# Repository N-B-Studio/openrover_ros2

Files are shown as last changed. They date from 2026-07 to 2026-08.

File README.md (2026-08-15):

# OpenRover ROS 2

A modular, full-stack mobile robotics platform combining STM32 firmware, Linux-based robot software, ROS 2 middleware, SLAM, and autonomous navigation.

The project provides two embedded controller options and two onboard computer configurations. Each layer is designed to remain modular, allowing different controllers, computers, and LiDAR sensors to be combined without rewriting the complete software stack.

## Platform Configurations

### OpenRover Light

A compact 2D SLAM and navigation platform designed for learning, development, and low-cost deployment.

**Hardware**

* STM32F103 motor controller
* JC FOC motor drivers
* Radxa ROCK 5C
* LD06 2D LiDAR
* Differential-drive chassis

**Current capabilities**

* Keyboard teleoperation
* Wheel odometry
* ROS 2 TF publishing
* 2D LiDAR visualization
* SLAM map generation
* Map saving and loading
* Nav2-based autonomous navigation

# [Watch the video](https://youtu.be/SysfDb_uuPQ)

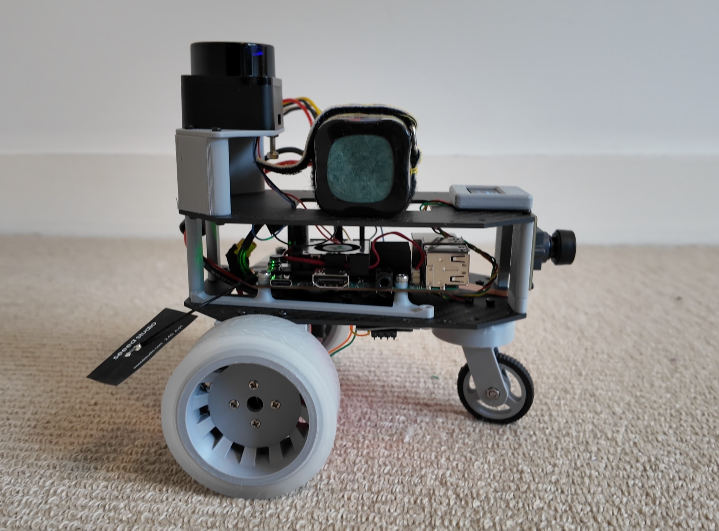
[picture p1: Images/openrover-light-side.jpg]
OpenRover Light side view


---

### OpenRover Plus

A higher-performance platform intended for 3D perception, sensor fusion, and more advanced autonomous robotics development.

**Planned hardware**

* STM32G431 motor controller
* Four integrated FOC wheel motors
* NVIDIA Jetson Orin Nano
* Livox Mid-360 3D LiDAR
* Intel RealSense D455 RGB-D camera
* BMI088 IMU

**Development goals**

* micro-ROS-based embedded communication
* Four-wheel skid-steer control
* IMU and wheel-odometry fusion
* 3D LiDAR SLAM
* RGB-coloured point clouds
* Autonomous exploration
* Navigation in unknown environments

**Status:** Under active development
**Demo video:** Coming soon
**Image:** Coming soon

## System Architecture

```mermaid
flowchart TD
    A["Sensors<br/>LD06 / Mid-360 / D455 / IMU"]
    B["Linux Computer<br/>ROCK 5C / Jetson Orin Nano"]
    C["ROS 2<br/>SLAM / Nav2 / Sensor Fusion"]
    D["Embedded Controller<br/>STM32F103 / STM32G431"]
    E["Motor Interface<br/>CAN / PWM + DIR"]
    F["FOC Motors"]

    A --> B
    B --> C
    C --> D
    D --> E
    E --> F
```

## Modular Design

OpenRover is not limited to fixed “Light” and “Plus” configurations.

The main components are designed as interchangeable layers:

| Layer | Available options |
| --- | --- |
| Embedded controller | STM32F103 or STM32G431 |
| Linux computer | Radxa ROCK 5C or NVIDIA Jetson Orin Nano |
| ROS 2 communication | UART text protocol or micro-ROS |
| LiDAR | LD06 2D LiDAR or Livox Mid-360 3D LiDAR |
| Camera | Intel RealSense D455 |
| Navigation | 2D SLAM and Nav2, with 3D autonomy planned |
| Motor control | CAN-based FOC control or 25 kHz PWM and direction control |

The long-term goal is to keep the ROS 2 interfaces consistent so that hardware components can be replaced without redesigning the entire application layer.

## Features

### Embedded Firmware

#### STM32F103

* CAN communication with FOC motor controllers
* UART command interface between Linux and STM32
* Plain-text velocity commands for debugging
* Motor command watchdog
* Wheel feedback reporting
* 0.96-inch OLED status display

#### STM32G431

* micro-ROS communication
* Four-wheel motor control
* 25 kHz PWM output
* Direction and brake control
* FG wheel-speed feedback
* Designed for odometry and diagnostic publishing

### ROS 2 Robot Software

* Differential-drive and skid-steer rover support
* `/cmd_vel` velocity command handling
* Wheel odometry publishing
* `odom -> base_link` TF publishing
* Robot description and RViz visualization
* Sensor drivers and launch files
* Keyboard teleoperation
* SLAM workflows
* Saved-map localization
* Nav2 navigation

### Perception and Autonomy

* LD06-based 2D mapping
* RViz goal-based navigation
* Obstacle-aware path planning
* Mid-360 3D perception integration — planned
* D455 RGB-D integration — planned
* RGB-coloured point-cloud mapping — planned
* Autonomous exploration — planned

## Repository Structure

```text
OpenRover/
├── G431CBU6-Rover/
│   └── STM32G431 rover firmware and related assets
├── STM32F103C8T6_ros2_car/
│   └── STM32F103 rover firmware
├── Linux/
│   └── ROS 2 workspaces, packages, launch files, and configuration
├── Ubuntu-22/
│   └── Additional Ubuntu-based ROS 2 development tools
├── Images/
│   └── Project photos, diagrams, and documentation assets
├── 3D model/
│   └── Rover chassis and wheel CAD assets
├── LICENSE
└── README.md
```

## Project Status

| Component | Status |
| --- | --- |
| STM32F103 motor control | Working |
| ROCK 5C ROS 2 integration | Working |
| Keyboard teleoperation | Working |
| Wheel odometry and TF | Working |
| LD06 visualization | Working |
| 2D SLAM | Working |
| Map saving and loading | Working |
| Nav2 integration | In progress |
| STM32G431 micro-ROS firmware | In progress |
| Four-wheel rover integration | In progress |
| IMU sensor fusion | Planned |
| Mid-360 3D SLAM | Planned |
| D455 colour point-cloud mapping | Planned |
| Autonomous exploration | Planned |

## Getting Started

Detailed setup guides will be provided for each supported configuration:

1. Build and flash the STM32 firmware.
2. Install ROS 2 on the onboard Linux computer.
3. Build the OpenRover ROS 2 workspace.
4. Connect the embedded controller and sensors.
5. Verify motor control, odometry, and TF.
6. Run teleoperation.
7. Build and save a map.
8. Launch localization and Nav2 navigation.

Configuration-specific instructions will be added under the relevant firmware and ROS 2 workspace directories.

## Roadmap

* [x] STM32F103 motor-control firmware
* [x] UART communication between ROS 2 and STM32
* [x] Wheel odometry and TF
* [x] LD06 integration
* [x] 2D SLAM workflow
* [ ] Complete and document Nav2 workflow
* [ ] Complete STM32G431 micro-ROS integration
* [ ] Add BMI088 IMU fusion
* [ ] Integrate Livox Mid-360
* [ ] Integrate Intel RealSense D455
* [ ] Generate RGB-coloured 3D point clouds
* [ ] Implement autonomous exploration
* [ ] Add automated tests and CI
* [ ] Publish complete build and demonstration videos

## Project Goals

OpenRover is both a practical robotics platform and a software-engineering portfolio project. It demonstrates experience across:

* C and C++ embedded development
* STM32 motor-control firmware
* ROS 2 node and interface design
* Linux robotics deployment
* Odometry and coordinate transforms
* SLAM and autonomous navigation
* Sensor integration and fusion
* Full-system debugging
* Simulation-to-real and hardware integration workflows

## License

This project is licensed under the MIT License. See [LICENSE](LICENSE) for details.

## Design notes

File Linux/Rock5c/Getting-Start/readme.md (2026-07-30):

# RoboNavLab DLC — LD06 2D SLAM & Autonomous Exploration

This DLC extends the frozen Stage 1 mobile base with an LD06 2D LiDAR, `slam_toolbox`, Nav2, and a frontier-exploration node.

## Final ROS 2 Architecture

```text
LD06
  |
  v
/scan ----------------------+
                            |
Stage 1 base                v
/cmd_vel <------------- Nav2 / Explorer
/odom ------------------+   |
/tf                     |   |
                        v   v
                    slam_toolbox
                        |
                        v
                      /map
                        |
                        +----> map_saver_cli
```

Target TF tree:

```text
map
└── odom
    └── base_link
        ├── left_wheel_link
        ├── right_wheel_link
        └── laser_frame
```

## Environment

Rock 5C:

```bash
source ~/ros2_humble/install/setup.bash
source ~/workspace/ros2_ws/install/setup.bash
export ROS_DOMAIN_ID=42
```

Ubuntu workstation:

```bash
source /opt/ros/<your-distro>/setup.bash
export ROS_DOMAIN_ID=42
```

## Start the Robot Base

On the Rock 5C:

```bash
ros2 launch ros_car_bringup car.launch.py
```

Verify:

```bash
ros2 topic hz /odom
ros2 topic echo /tf --once
ros2 run tf2_ros tf2_echo odom base_link
```

## Start the LD06 Driver

Run:
```bash
source ~/ros2_humble/install/setup.bash
source ~/workspace/ros2_ws/install/setup.bash
export ROS_DOMAIN_ID=42

ros2 run tf2_ros static_transform_publisher \
  --x -0.007 \
  --y 0.0 \
  --z 0.125 \
  --roll 0 \
  --pitch 0 \
  --yaw 0 \
  --frame-id base_link \
  --child-frame-id laser_frame
```

The final DLC will expose the LiDAR as:

```text
/scan
```

Verify:

```bash
ros2 topic list | grep scan
ros2 topic hz /scan
ros2 topic echo /scan --once
```

The `LaserScan.header.frame_id` must match the LiDAR TF frame, for example:

```text
laser_frame
```

## Start 2D SLAM

After the DLC packages and configuration are built:

```bash
ros2 launch ros_car_navigation slam.launch.py
```

Verify:

```bash
ros2 topic list | grep map
ros2 run tf2_ros tf2_echo map odom
```

Expected important topics:

```text
/scan
/odom
/map
/map_metadata
/tf
/tf_static
```

## Manual Mapping Test

Use keyboard teleoperation from the workstation:

```bash
ros2 run teleop_twist_keyboard teleop_twist_keyboard
```

Drive slowly around the room and verify that the occupancy grid grows in RViz.

Recommended RViz displays:

```text
Map        -> /map
LaserScan  -> /scan
RobotModel
TF
Odometry
```

Set:

```text
Fixed Frame = map
```

## Save the Map Locally

Create a map directory:

```bash
mkdir -p ~/workspace/ros2_ws/maps
```

Save the current occupancy map:

```bash
ros2 run nav2_map_server map_saver_cli \
  -f ~/workspace/ros2_ws/maps/room
```

Expected files:

```text
~/workspace/ros2_ws/maps/room.yaml
~/workspace/ros2_ws/maps/room.pgm
```

## Start Autonomous Exploration

After the exploration lesson is complete:

```bash
ros2 launch ros_car_navigation explore.launch.py
```

The exploration node will:

1. Read the current occupancy grid.
2. Find frontiers between known free space and unknown space.
3. Select a reachable frontier.
4. Send a Nav2 `NavigateToPose` goal.
5. Wait for the robot to reach or fail the goal.
6. Select the next frontier.
7. Stop when no useful frontiers remain.

Keep an emergency-stop terminal ready:

```bash
ros2 topic pub --once /cmd_vel geometry_msgs/msg/Twist "{}"
```

For first autonomous tests, keep the robot in a clear room and use conservative speed limits.

## Save the Automatically Built Map

When exploration is finished:

```bash
ros2 run nav2_map_server map_saver_cli \
  -f ~/workspace/ros2_ws/maps/room_auto
```

## Basic Health Checks

```bash
ros2 node list
ros2 topic hz /scan
ros2 topic hz /odom
ros2 topic hz /map
ros2 run tf2_ros tf2_echo odom base_link
ros2 run tf2_ros tf2_echo base_link laser_frame
ros2 run tf2_ros tf2_echo map odom
```

## Expected Final Packages

```text
ros_car_base/          # Stage 1 base driver
ros_car_description/   # URDF / TF
ros_car_bringup/       # Stage 1 bringup
ros_car_lidar/         # LD06 launch/config
ros_car_navigation/    # slam_toolbox + Nav2 + map save
ros_car_exploration/   # frontier explorer
```

## Final Demo

```text
Power on robot
    |
    v
Stage 1 bringup
    |
    v
LD06 /scan
    |
    v
slam_toolbox
    |
    v
Nav2 + frontier exploration
    |
    v
Robot autonomously explores room
    |
    v
room_auto.yaml + room_auto.pgm
```

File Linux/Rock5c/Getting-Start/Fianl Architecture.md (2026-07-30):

Robot: Rock 5C
────────────────────────────
STM32 base controller
LD06 driver
base_driver
robot_state_publisher
static/dynamic TF publishers
hardware watchdog
sensor diagnostics

Publishes:
  /scan
  /odom
  /tf
  /tf_static
  /joint_states
  /diagnostics

Subscribes:
  /cmd_vel

             DDS network

Workstation: Ubuntu PC
────────────────────────────
RViz
slam_toolbox
map saver
Nav2
rosbag2
diagnostic tools
later perception workloads

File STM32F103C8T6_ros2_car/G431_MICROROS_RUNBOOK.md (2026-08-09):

# G431 Four-Wheel Rover Base — micro-ROS Runbook

Status: **frozen baseline (`g431-base-v1.0`)**  
Target: STM32G431 + Jetson, ROS 2 Humble, micro-ROS serial transport

## 1. Frozen ROS 2 interface

The MCU intentionally exposes only the minimum base interface:

| Direction | Topic | Type | Purpose |
|---|---|---|---|
| Jetson → G431 | `/cmd_vel` | `geometry_msgs/msg/Twist` | Linear and angular velocity command |
| G431 → Jetson | `/wheel_states` | `sensor_msgs/msg/JointState` | Four-wheel position and velocity feedback |

Expected node name:

```text
/g431_rover_base
```

`/wheel_states` joint order:

```text
front_left_wheel_joint
rear_left_wheel_joint
front_right_wheel_joint
rear_right_wheel_joint
```

## 2. Safety and timing contract

- The MCU stops the motors if no `/cmd_vel` arrives for **200 ms**.
- The command source must continuously publish at **10–20 Hz**; **20 Hz is recommended**.
- Do not use 2 Hz: one message arrives every 500 ms, so the 200 ms watchdog repeatedly stops the motors for about 300 ms. This causes the observed start-stop motion and is expected behavior.
- The firmware retains the **300 ms direction-change protection**, 30 RPM limit, and calibrated PWM–RPM mapping.
- Stopping the command publisher must stop the rover within approximately 200 ms.
- This software watchdog is not a substitute for a physical emergency stop.

## 3. One-time Jetson prerequisites

Confirm the serial device:

```bash
ls -l /dev/ttyACM0
```

Confirm the user can access it:

```bash
groups
```

If the device changes after reconnecting, identify it with:

```bash
ls -l /dev/serial/by-id/
```

Prefer the stable `/dev/serial/by-id/...` path in scripts when available.

## 4. Start the native micro-ROS Agent

Terminal 1:

```bash
source /opt/ros/humble/setup.bash

ros2 run micro_ros_agent micro_ros_agent serial \
  --dev /dev/ttyACM0 \
  -b 115200 \
  -v4
```

Keep this terminal running while the G431 communicates with ROS 2. Only one Agent may open the serial port at a time.

For detailed diagnosis, temporarily replace `-v4` with `-v6`.

## 5. Optional Docker Agent

Use this only if the native Agent is unavailable. Do not run it at the same time as the native Agent.

```bash
docker run -it --rm \
  --net=host \
  --privileged \
  -v /dev:/dev \
  microros/micro-ros-agent:humble \
  serial \
  --dev /dev/ttyACM0 \
  -b 115200 \
  -v4
```

## 6. Verify the frozen interface

Terminal 2:

```bash
source /opt/ros/humble/setup.bash
source ~/workspace/ros2_ws/install/setup.bash

ros2 daemon stop
ros2 daemon start
ros2 node info /g431_rover_base
ros2 topic list -t
```

Expected node interface:

```text
Subscribers:
  /cmd_vel: geometry_msgs/msg/Twist
Publishers:
  /wheel_states: sensor_msgs/msg/JointState
```

Verify feedback:

```bash
ros2 topic hz /wheel_states
```

Expected rate: approximately **10 Hz** (measured baseline: **9.92 Hz**).

```bash
ros2 topic echo /wheel_states --once
```

Confirm:

- `header.stamp` is non-zero;
- `frame_id` is `base_link`;
- all four joint names are present;
- positions accumulate when wheels rotate;
- velocities update with the correct sign.

## 7. Safe bench motion test

Raise all four wheels off the ground before the first test.

Forward at 20 Hz:

```bash
ros2 topic pub -r 20 /cmd_vel geometry_msgs/msg/Twist \
  "{linear: {x: 0.10}, angular: {z: 0.0}}"
```

Stop the publisher with `Ctrl+C`. The wheels must stop within approximately 200 ms.

Pure rotation test:

```bash
ros2 topic pub -r 20 /cmd_vel geometry_msgs/msg/Twist \
  "{linear: {x: 0.0}, angular: {z: 0.5}}"
```

Publish an explicit zero command if required:

```bash
ros2 topic pub --once /cmd_vel geometry_msgs/msg/Twist \
  "{linear: {x: 0.0}, angular: {z: 0.0}}"
```

## 8. Check the command source

While teleoperation or autonomy is active:

```bash
ros2 topic hz /cmd_vel
```

Healthy baseline:

```text
average rate: approximately 20 Hz
min/max interval: approximately 0.050 s
```

Long gaps greater than 0.200 s trigger the watchdog. A low average caused by stopping and restarting the publisher is not a transport fault; inspect the `max` interval and observe the rate while commands are actively being sent.

## 9. Common faults

### `/wheel_states` is listed but no samples arrive

- Confirm the Agent is still running.
- Confirm the G431 is powered and connected.
- Ensure only one Agent owns `/dev/ttyACM0`.
- Restart the Agent, power-cycle the G431, and repeat the interface check.
- Use Agent verbosity `-v6` for entity-creation and transport logs.

### Two nodes have the same `/g431_rover_base` name

Stop duplicate Agents, then refresh discovery:

```bash
ros2 daemon stop
ros2 daemon start
```

Power-cycle the G431 and start exactly one Agent.

### Motors pulse or repeatedly start and stop

Measure `/cmd_vel`. If it is below 5 Hz or has gaps over 200 ms, the watchdog is operating correctly. Run the command source continuously at 10–20 Hz; 20 Hz is recommended.

### Agent reports that the serial port is busy

Find the process holding it:

```bash
lsof /dev/ttyACM0
```

Stop the older Agent process before starting another one.

## 10. Freeze checklist

Before tagging the repository:

- Release firmware builds and flashes successfully.
- `/g431_rover_base` has exactly one subscriber and one publisher.
- `/wheel_states` is stable near 10 Hz.
- Joint names, timestamp, frame, positions, and velocities are valid.
- A fixed command at 20 Hz produces smooth motion.
- Ending `/cmd_vel` publication stops the base within about 200 ms.
- Forward, reverse, and pure rotation directions are correct with the rover lifted.
- Firmware source, CubeMX configuration, linker/micro-ROS files, and this runbook are committed together.

Suggested Git tag:

```bash
git tag -a g431-base-v1.0 -m "Freeze G431 micro-ROS rover base interface"
git push origin g431-base-v1.0
```

Do not change the frozen MCU interface during the next stage. Implement odometry and TF on the Jetson using `/wheel_states` as the input.

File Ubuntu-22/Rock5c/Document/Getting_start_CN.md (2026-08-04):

下面是一套从零开始、按终端编号执行的完整流程。照这个顺序启动，就不会再丢步骤。

# A. Rock 5C 端

## Terminal R1 — 启动小车基础节点

```bash
source ~/ros2_humble/install/setup.bash
source ~/workspace/ros2_ws/install/setup.bash

export ROS_DOMAIN_ID=42
export ROS_LOCALHOST_ONLY=0
```

启动你现有的 Stage 1 bringup：

```bash
ros2 launch ros_car_bringup car.launch.py
```

如果你的 launch 文件名不是这个，使用你之前已经能启动：

```text
/base_driver
/robot_state_publisher
```

的那个命令。

验证：

```bash
ros2 node list
```

至少应看到：

```text
/base_driver
/robot_state_publisher
```

检查里程计：

```bash
ros2 topic hz /odom
```

目标：

```text
约 44 Hz
```

---

## Terminal R2 — 启动 LD06

```bash
source ~/ros2_humble/install/setup.bash
source ~/workspace/ros2_ws/install/setup.bash

export ROS_DOMAIN_ID=42
export ROS_LOCALHOST_ONLY=0
```

启动：

```bash
ros2 launch ldlidar ldlidar.launch.py \
  serial_port:=/dev/ttyS6 \
  lidar_frame:=laser_frame \
  topic_name:=scan
```

正常日志应包含：

```text
Using port /dev/ttyS6
LiDAR_LD06 started successfully
```

保持该终端运行。

---

## Terminal R3 — 发布 LiDAR 静态 TF

```bash
source ~/ros2_humble/install/setup.bash
source ~/workspace/ros2_ws/install/setup.bash

export ROS_DOMAIN_ID=42
export ROS_LOCALHOST_ONLY=0
```

运行：

```bash
ros2 run tf2_ros static_transform_publisher \
  --x -0.007 \
  --y 0.0 \
  --z 0.125 \
  --roll 0 \
  --pitch 0 \
  --yaw 1.57079632679 \
  --frame-id base_link \
  --child-frame-id laser_frame
```

保持该终端运行。

---

## Terminal R4 — Rock 端总检查

```bash
source ~/ros2_humble/install/setup.bash
source ~/workspace/ros2_ws/install/setup.bash

export ROS_DOMAIN_ID=42
export ROS_LOCALHOST_ONLY=0
```

检查 `/scan`：

```bash
ros2 topic hz /scan
```

应约为：

```text
10 Hz
```

检查 `/odom`：

```bash
ros2 topic hz /odom
```

应约为：

```text
44 Hz
```

检查完整 TF：

```bash
ros2 run tf2_ros tf2_echo odom laser_frame
```

应持续输出类似：

```text
Translation: [-0.007, 0.000, 0.125]
```

如果这三项通过，Rock 端完成。

不要在 Rock 上启动：

```bash
ros2 launch ros_car_navigation slam.launch.py
```

因为 SLAM 由 laptop 运行。

---

# B. Laptop 端

## Terminal P1 — 检查 Rock 数据

```bash
source /opt/ros/humble/setup.bash

export ROS_DOMAIN_ID=42
export ROS_LOCALHOST_ONLY=0
```

建议重启 daemon：

```bash
ros2 daemon stop
sleep 2
ros2 daemon start
sleep 2
```

检查雷达：

```bash
ros2 topic hz /scan
```

应约为：

```text
10 Hz
```

检查里程计：

```bash
ros2 topic hz /odom
```

应约为：

```text
44 Hz
```

检查 TF：

```bash
ros2 run tf2_ros tf2_echo odom laser_frame
```

必须持续输出。

只有这三项都正常，才继续 SLAM。

---

## Terminal P2 — 启动 SLAM Toolbox

```bash
source /opt/ros/humble/setup.bash

export ROS_DOMAIN_ID=42
export ROS_LOCALHOST_ONLY=0
```

启动：

```bash
ros2 launch slam_toolbox online_async_launch.py \
  use_sim_time:=false \
  slam_params_file:=$HOME/workspace/ros_car_demo/config/slam_params.yaml
```

保持运行。

正常日志应包含：

```text
Using solver plugin solver_plugins::CeresSolver
```

---

## Terminal P3 — 检查 SLAM

```bash
source /opt/ros/humble/setup.bash

export ROS_DOMAIN_ID=42
export ROS_LOCALHOST_ONLY=0
```

检查地图 topic：

```bash
ros2 topic list | grep -E "map|scan"
```

应看到：

```text
/map
/map_metadata
/scan
```

检查 SLAM 是否订阅 `/scan`：

```bash
ros2 topic info /scan -v
```

应至少有：

```text
Publisher count: 1
Subscription count: 1
```

检查 `map -> odom`：

```bash
ros2 run tf2_ros tf2_echo map odom
```

一旦这个开始持续输出，说明 SLAM 正常工作。

---

## Terminal P4 — 启动 RViz2

```bash
source /opt/ros/humble/setup.bash

export ROS_DOMAIN_ID=42
export ROS_LOCALHOST_ONLY=0

rviz2
```

RViz 设置：

```text
Fixed Frame = map
```

添加：

```text
Map
LaserScan
RobotModel
TF
Odometry
Grid
```

对应 Topic：

```text
Map        = /map
LaserScan  = /scan
Odometry   = /odom
```

如果刚启动时提示：

```text
Frame [map] does not exist
```

先等待几秒。

如果仍然不存在，回 Terminal P3 检查：

```bash
ros2 run tf2_ros tf2_echo map odom
```

---

## Terminal P5 — 键盘控制建图

```bash
source /opt/ros/humble/setup.bash

export ROS_DOMAIN_ID=42
export ROS_LOCALHOST_ONLY=0
```

启动：

```bash
ros2 run teleop_twist_keyboard teleop_twist_keyboard
```

按键：

```text
i = 前进
, = 后退
j = 左转
l = 右转
k = 停止
```

建议速度：

```text
Linear  = 0.10–0.15 m/s
Angular = 0.20–0.30 rad/s
```

推荐建图路线：

```text
1. 静止 5–10 秒
2. 缓慢直行
3. 缓慢转弯
4. 沿房间边缘走
5. 尽量回到起点
6. 等待 loop closure
```

避免：

```text
快速旋转
急加速
轮胎打滑
抬起机器人
手推机器人
```

---

# C. 地图不好时重新开始

只停止 laptop 上的 SLAM Toolbox。

在 Terminal P2 按：

```text
Ctrl+C
```

然后重新运行：

```bash
ros2 launch slam_toolbox online_async_launch.py \
  use_sim_time:=false \
  slam_params_file:=$HOME/workspace/ros_car_demo/config/slam_params.yaml
```

这会创建一张新的空地图。

以下节点不需要重启：

```text
Rock base_driver
Rock robot_state_publisher
Rock LD06
Rock laser TF
Laptop RViz
Laptop keyboard teleop
```

RViz 可以保持打开。

---

# D. 保存地图

## Terminal P6 — 保存最终地图

```bash
source /opt/ros/humble/setup.bash

export ROS_DOMAIN_ID=42
export ROS_LOCALHOST_ONLY=0
```

创建目录：

```bash
mkdir -p ~/workspace/ros_car_demo/maps
```

保存：

```bash
ros2 run nav2_map_server map_saver_cli \
  -f ~/workspace/ros_car_demo/maps/room_map
```

生成：

```text
~/workspace/ros_car_demo/maps/room_map.yaml
~/workspace/ros_car_demo/maps/room_map.pgm
```

检查：

```bash
ls -lh ~/workspace/ros_car_demo/maps
```

---

# 最终启动顺序速查

## Rock 5C

```text
R1: base bringup
R2: LD06
R3: base_link -> laser_frame
R4: diagnostics
```

## Laptop

```text
P1: verify /scan, /odom, TF
P2: slam_toolbox
P3: verify /map and map -> odom
P4: RViz2
P5: keyboard teleop
P6: save map
```

最关键的启动顺序是：

```text
1. Rock base
2. Rock LD06
3. Rock laser TF
4. Laptop verify data
5. Laptop SLAM
6. Laptop verify map -> odom
7. Laptop RViz
8. Laptop keyboard control
9. Save map
```

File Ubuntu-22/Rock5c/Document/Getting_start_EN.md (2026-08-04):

====================== Rock 5c: =====================
## terminal 1:
source ~/ros2_humble/install/setup.bash
source ~/workspace/ros2_ws/install/setup.bash

export ROS_DOMAIN_ID=42
export ROS_LOCALHOST_ONLY=0

ros2 launch ros_car_navigation explore.launch.py

## terminal 2:
source ~/ros2_humble/install/setup.bash
source ~/workspace/ros2_ws/install/setup.bash
export ROS_DOMAIN_ID=42

ros2 run tf2_ros static_transform_publisher \
  --x -0.007 \
  --y 0.0 \
  --z 0.125 \
  --roll 0 \
  --pitch 0 \
  --yaw 0 \
  --frame-id base_link \
  --child-frame-id laser_frame

## terminal 3:
source ~/ros2_humble/install/setup.bash
source ~/workspace/ros2_ws/install/setup.bash

export ROS_DOMAIN_ID=42
export ROS_LOCALHOST_ONLY=0

ros2 launch ldlidar ldlidar.launch.py \
  serial_port:=/dev/ttyS6 \
  lidar_frame:=laser_frame \
  topic_name:=scan
## terminal 4:
source ~/ros2_humble/install/setup.bash
source ~/workspace/ros2_ws/install/setup.bash

export ROS_DOMAIN_ID=42
export ROS_LOCALHOST_ONLY=0

ros2 node list
ros2 topic hz /scan

=========================== PC: ===========================
## terminal 1:
# Srouce
source /opt/ros/humble/setup.bash
echo $ROS_DISTRO

# set network
export ROS_DOMAIN_ID=42
export ROS_LOCALHOST_ONLY=0

# restart daemon
ros2 daemon stop
sleep 2
ros2 daemon start
sleep 2

# check scan hz, should be 10 hz
ros2 topic hz /scan

# check node list
ros2 node list

# install SLAM Toolbox
ros2 pkg list | grep slam_toolbox

# install if no output:
sudo apt update
sudo apt install -y ros-humble-slam-toolbox

# create SLAM setting:
mkdir -p ~/workspace/ros_car_demo/config
# create ymal
nano ~/workspace/ros_car_demo/config/slam_params.yaml
# add:
slam_toolbox:
  ros__parameters:
    solver_plugin: solver_plugins::CeresSolver
    ceres_linear_solver: SPARSE_NORMAL_CHOLESKY
    ceres_preconditioner: SCHUR_JACOBI
    ceres_trust_strategy: LEVENBERG_MARQUARDT
    ceres_dogleg_type: TRADITIONAL_DOGLEG
    ceres_loss_function: None

    odom_frame: odom
    map_frame: map
    base_frame: base_link
    scan_topic: /scan

    mode: mapping
    use_sim_time: false

    use_map_saver: true
    debug_logging: false
    throttle_scans: 1

    transform_publish_period: 0.05
    map_update_interval: 1.0
    resolution: 0.05

    min_laser_range: 0.05
    max_laser_range: 12.0

    minimum_time_interval: 0.10
    transform_timeout: 0.5
    tf_buffer_duration: 30.0

    stack_size_to_use: 40000000
    enable_interactive_mode: true

    use_scan_matching: true
    use_scan_barycenter: true

    minimum_travel_distance: 0.05
    minimum_travel_heading: 0.05

    scan_buffer_size: 10
    scan_buffer_maximum_scan_distance: 10.0

    link_match_minimum_response_fine: 0.1
    link_scan_maximum_distance: 1.5

    loop_search_maximum_distance: 3.0
    do_loop_closing: true
    loop_match_minimum_chain_size: 10
    loop_match_maximum_variance_coarse: 3.0
    loop_match_minimum_response_coarse: 0.35
    loop_match_minimum_response_fine: 0.45
## terminal 2:
# Start SLAM
source /opt/ros/humble/setup.bash

export ROS_DOMAIN_ID=42
export ROS_LOCALHOST_ONLY=0

ros2 launch slam_toolbox online_async_launch.py \
  use_sim_time:=false \
  slam_params_file:=$HOME/workspace/ros_car_demo/config/slam_params.yaml

# should include:
Using solver plugin solver_plugins::CeresSolver

## terminal 3:
# confirm SLAM
source /opt/ros/humble/setup.bash

export ROS_DOMAIN_ID=42
export ROS_LOCALHOST_ONLY=0
# check
ros2 topic list | grep -E "map|scan"
# should show:
/map
/map_metadata
/scan

# check lidar topic:
ros2 topic info /scan -v

# should be:
Publisher count: 1
Subscription count: 1

# check TF:
ros2 run tf2_ros tf2_echo map odom

* should be:
* map -> odom

## terminal 4:

# start RViz2
source /opt/ros/humble/setup.bash

export ROS_DOMAIN_ID=42
export ROS_LOCALHOST_ONLY=0

rviz2

# rviz2 setting:
* Fixed Frame = map

add:

* Map
* LaserScan
* RobotModel
* TF
* Odometry
* Grid

Topics：
* Map        = /map
* LaserScan  = /scan
* Odometry   = /odom

## Terminal 5: Keyboard controll

# install: 
sudo apt install -y ros-humble-teleop-twist-keyboard

# start:
source /opt/ros/humble/setup.bash

export ROS_DOMAIN_ID=42
export ROS_LOCALHOST_ONLY=0

ros2 run teleop_twist_keyboard teleop_twist_keyboard

## Rebuild map:
ros2 launch slam_toolbox online_async_launch.py \
  use_sim_time:=false \
  slam_params_file:=$HOME/workspace/ros_car_demo/config/slam_params.yaml

## save map:
地图满意后，在 laptop 执行：

mkdir -p ~/workspace/ros_car_demo/maps

保存：

ros2 run nav2_map_server map_saver_cli \
  -f ~/workspace/ros_car_demo/maps/room_map

如果没有 nav2_map_server：

sudo apt install -y ros-humble-nav2-map-server

生成：

~/workspace/ros_car_demo/maps/room_map.yaml
~/workspace/ros_car_demo/maps/room_map.pgm

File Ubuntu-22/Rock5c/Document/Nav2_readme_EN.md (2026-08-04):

This is the README I would put in your GitHub repository. It assumes a user has already cloned your ROS2 car project and has successfully built both the Rock 5C and PC workspaces.

---

# ROS 2 Differential Drive Robot Navigation (LD06 + Nav2)

This project demonstrates a complete ROS 2 navigation pipeline using:

* Rock 5C onboard computer
* STM32 differential-drive controller
* LD06 2D LiDAR
* ROS 2 Humble
* SLAM Toolbox
* Nav2
* RViz2

The robot publishes all sensor data over WiFi while all heavy computation runs on a desktop PC.

## System Architecture

```
                 WiFi DDS

        Rock 5C
+----------------------------+
| Base Driver                |
| Robot State Publisher      |
| LD06 Driver                |
| Static TF                  |
+-------------+--------------+
              |
        /scan /odom /tf
              |
=============================
              |
        Desktop PC
+----------------------------+
| SLAM Toolbox               |
| RViz2                      |
| Map Server                 |
| AMCL                       |
| Nav2                       |
| Teleop                     |
+----------------------------+
```

The robot only performs low-level hardware control.

The desktop PC performs:

* Mapping
* Localization
* Global planning
* Local planning
* Navigation
* Visualization

---

# Requirements

## Robot

* Rock 5C
* ROS2 Humble
* LD06 LiDAR
* STM32 base controller
* WiFi connection

## PC

Ubuntu 22.04

ROS2 Humble

Packages

```
slam_toolbox
navigation2
nav2_bringup
rviz2
teleop_twist_keyboard
```

---

# Coordinate Frames

```
map
 └── odom
      └── base_link
            ├── laser_frame
            ├── camera_link
            ├── left_wheel
            └── right_wheel
```

Robot origin:

```
base_link
```

LD06 position:

```
X = -0.007 m
Y = 0
Z = 0.125 m
```

---

# Step 1 — Start Robot

Terminal 1

Launch base driver.

```bash
source ~/workspace/ros2_ws/install/setup.bash

export ROS_DOMAIN_ID=42
export ROS_LOCALHOST_ONLY=0

ros2 launch base_driver bringup.launch.py
```

---

Terminal 2

Launch LD06.

```bash
source ~/ros2_humble/install/setup.bash
source ~/workspace/ros2_ws/install/setup.bash

export ROS_DOMAIN_ID=42
export ROS_LOCALHOST_ONLY=0

ros2 launch ldlidar ldlidar.launch.py \
serial_port:=/dev/ttyS6 \
lidar_frame:=laser_frame \
topic_name:=scan
```

---

Terminal 3

Publish the static transform.

```bash
source ~/ros2_humble/install/setup.bash

ros2 run tf2_ros static_transform_publisher \
--x -0.007 \
--y 0 \
--z 0.125 \
--roll 0 \
--pitch 0 \
--yaw 0 \
--frame-id base_link \
--child-frame-id laser_frame
```

Verify

```
/scan
/odom
/tf
```

---

# Step 2 — Build a Map

Desktop PC

Terminal 1

```bash
source /opt/ros/humble/setup.bash

export ROS_DOMAIN_ID=42
export ROS_LOCALHOST_ONLY=0

ros2 launch slam_toolbox online_async_launch.py \
use_sim_time:=false \
slam_params_file:=~/workspace/ros_car_demo/config/slam_params.yaml
```

---

Terminal 2

```bash
rviz2
```

Set

```
Fixed Frame = map
```

Add

```
Map
LaserScan
RobotModel
TF
Odometry
```

---

Terminal 3

Drive robot.

```bash
ros2 run teleop_twist_keyboard teleop_twist_keyboard
```

Drive around slowly until the map is complete.

---

# Step 3 — Save the Map

Stop driving.

Open another terminal.

```bash
source /opt/ros/humble/setup.bash

ros2 run nav2_map_server map_saver_cli \
-f ~/workspace/ros_car_demo/maps/room_map
```

Generated files

```
room_map.yaml
room_map.pgm
```

Verify

```
ls maps
```

---

# Step 4 — Stop SLAM

Stop

```
SLAM Toolbox
RViz
Teleop
```

The saved map will now be used for localization.

---

# Step 5 — Load the Map

Terminal 1

```bash
source /opt/ros/humble/setup.bash

ros2 launch nav2_bringup localization_launch.py \
map:=~/workspace/ros_car_demo/maps/room_map.yaml \
params_file:=~/workspace/ros_car_demo/config/localization_params.yaml \
use_sim_time:=false \
autostart:=true
```

Verify

```
ros2 node list
```

Should contain

```
map_server
amcl
```

---

# Step 6 — Start Navigation

Open another terminal.

```bash
source /opt/ros/humble/setup.bash

ros2 launch nav2_bringup navigation_launch.py \
use_sim_time:=false \
autostart:=true \
params_file:=~/workspace/ros_car_demo/config/nav2_params.yaml
```

Verify

```
planner_server
controller_server
bt_navigator
behavior_server
```

are running.

---

# Step 7 — Open RViz

```bash
rviz2 \
-d /opt/ros/humble/share/nav2_bringup/rviz/nav2_default_view.rviz
```

Set

```
Fixed Frame = map
```

Add if necessary

```
Map
LaserScan
TF
RobotModel
Global Costmap
Local Costmap
```

---

# Step 8 — Initial Localization

Use

```
2D Pose Estimate
```

Click the robot location on the map.

Drag to match the robot heading.

After a few seconds,

LaserScan should align with walls.

AMCL particles should converge.

---

# Step 9 — Navigate

Click

```
Nav2 Goal
```

(or **2D Goal Pose** depending on the RViz configuration.)

Choose a destination.

Nav2 will automatically

* plan a path
* avoid obstacles
* publish `/cmd_vel`
* drive the robot to the goal

---

# Verify Navigation

Robot

```
ros2 topic hz /scan
```

should be approximately

```
10 Hz
```

Robot odometry

```
ros2 topic hz /odom
```

should be approximately

```
44 Hz
```

Navigation

```
ros2 topic echo /cmd_vel
```

should publish velocity commands while navigating.

TF Tree

```
map
 └── odom
      └── base_link
            └── laser_frame
```

---

# Project Structure

```
ros_car_demo/

├── config/
│   ├── slam_params.yaml
│   ├── localization_params.yaml
│   └── nav2_params.yaml
│
├── maps/
│   ├── room_map.yaml
│   └── room_map.pgm
│
└── README.md
```

---

# Current Features

* ROS2 Differential Drive Robot
* WiFi DDS Communication
* LD06 LiDAR Driver
* Static TF Configuration
* Robot URDF
* Odometry
* SLAM Toolbox Mapping
* Map Saving
* AMCL Localization
* Nav2 Autonomous Navigation
* RViz2 Visualization

---

## Future Roadmap

* Camera streaming over WiFi (Rock 5C → PC)
* YOLO object detection on desktop GPU
* Automatic object following
* Loop closure optimization
* Multi-floor mapping
* Fast-LIO2 with Livox Mid-360
* D455 RGB point cloud colorization
* Autonomous exploration
* GPS waypoint navigation (outdoor)
* Migration to PX4 autonomous mobile robot/UAV platform

This README reflects the final architecture you built during the course: **the Rock 5C is responsible only for real-time sensing and control, while the desktop PC performs SLAM, localization, planning, AI, and visualization.** This is also the architecture commonly used on larger research robots where compute-intensive workloads are offloaded from the embedded computer.

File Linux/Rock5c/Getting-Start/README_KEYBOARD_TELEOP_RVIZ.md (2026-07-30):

# ROS 2 Keyboard Teleoperation and RViz Demo

This is the minimal version of the project.

It allows a user to:

- start the robot on the Rock 5C;
- control the car from the PC keyboard;
- view the robot model, odometry, TF, and grid in RViz2;
- run without the LD06 LiDAR, SLAM Toolbox, or Nav2.

---

## 1. Architecture

```text
Rock 5C — ROS 2 Humble
├── base_driver
│   ├── subscribes: /cmd_vel
│   ├── publishes:  /odom
│   └── publishes:  odom -> base_link
│
└── robot_state_publisher
    ├── publishes: /robot_description
    ├── publishes: /tf
    └── publishes: /tf_static

             ROS 2 DDS over LAN

Ubuntu PC — ROS 2 Jazzy
├── teleop_twist_keyboard
│   └── publishes: /cmd_vel
│
└── RViz2
    ├── Fixed Frame: odom
    ├── Grid
    ├── RobotModel
    ├── TF
    └── Odometry
```

No LiDAR is required.

No SLAM is required.

No map frame is required.

---

## 2. Requirements

### Rock 5C

- Debian 12
- ROS 2 Humble
- built robot workspace
- STM32 base controller connected
- working motor driver
- working odometry publisher

### Ubuntu PC

- Ubuntu 24.04
- ROS 2 Jazzy
- RViz2
- `teleop_twist_keyboard`

Install PC packages:

```bash
sudo apt update

sudo apt install -y \
  ros-jazzy-rviz2 \
  ros-jazzy-teleop-twist-keyboard
```

---

## 3. Clone and Build the Repository

Run this on both the Rock 5C and the PC.

```bash
mkdir -p ~/workspace
cd ~/workspace

git clone <YOUR_GITHUB_REPOSITORY_URL> ros2_ws
cd ~/workspace/ros2_ws
```

### Rock 5C build

```bash
source ~/ros2_humble/install/setup.bash

rosdep install \
  --from-paths src \
  --ignore-src \
  --rosdistro humble \
  -r \
  -y

colcon build --symlink-install

source ~/workspace/ros2_ws/install/setup.bash
```

### PC build

If the PC only needs the robot description package:

```bash
source /opt/ros/jazzy/setup.bash

rosdep install \
  --from-paths src \
  --ignore-src \
  --rosdistro jazzy \
  -r \
  -y

colcon build \
  --symlink-install \
  --packages-select ros_car_description

source ~/workspace/ros2_ws/install/setup.bash
```

---

## 4. Configure ROS 2 Networking

Use the same settings on both machines.

```bash
export ROS_DOMAIN_ID=42
unset ROS_LOCALHOST_ONLY
export ROS_AUTOMATIC_DISCOVERY_RANGE=SUBNET
```

Optional: add them to `~/.bashrc`.

```bash
cat >> ~/.bashrc <<'EOF'

# ROS 2 distributed robot network
export ROS_DOMAIN_ID=42
unset ROS_LOCALHOST_ONLY
export ROS_AUTOMATIC_DISCOVERY_RANGE=SUBNET
EOF
```

Reload:

```bash
source ~/.bashrc
```

Verify:

```bash
echo "$ROS_DOMAIN_ID"
echo "$ROS_AUTOMATIC_DISCOVERY_RANGE"
```

Expected:

```text
42
SUBNET
```

Confirm the PC can reach the Rock 5C:

```bash
ping <ROCK_5C_IP>
```

---

# 5. Start the Robot on the Rock 5C

## Preferred command

The preferred bringup launch should start:

```text
base_driver
robot_state_publisher
```

Run:

```bash
source ~/ros2_humble/install/setup.bash
source ~/workspace/ros2_ws/install/setup.bash

export ROS_DOMAIN_ID=42
unset ROS_LOCALHOST_ONLY
export ROS_AUTOMATIC_DISCOVERY_RANGE=SUBNET

ros2 launch ros_car_bringup base.launch.py
```

The launch file should not start:

```text
LD06
SLAM Toolbox
Nav2
RViz2
```

---

## Manual fallback

Use separate terminals if the bringup launch file does not exist yet.

### Rock terminal R1 — base driver

```bash
source ~/ros2_humble/install/setup.bash
source ~/workspace/ros2_ws/install/setup.bash

export ROS_DOMAIN_ID=42
unset ROS_LOCALHOST_ONLY
export ROS_AUTOMATIC_DISCOVERY_RANGE=SUBNET

ros2 run ros_car_base base_driver
```

Check the available executable name if required:

```bash
ros2 pkg executables ros_car_base
```

### Rock terminal R2 — robot description

```bash
source ~/ros2_humble/install/setup.bash
source ~/workspace/ros2_ws/install/setup.bash

export ROS_DOMAIN_ID=42
unset ROS_LOCALHOST_ONLY
export ROS_AUTOMATIC_DISCOVERY_RANGE=SUBNET

ros2 launch ros_car_description display.launch.py
```

If the repository uses a different launch filename:

```bash
find ~/workspace/ros2_ws/src/ros_car_description \
  -maxdepth 3 \
  -type f
```

---

## Verify the Rock 5C

```bash
ros2 node list
```

Expected nodes:

```text
/base_driver
/robot_state_publisher
```

Check odometry:

```bash
ros2 topic hz /odom
```

Expected:

```text
approximately 44 Hz
```

Check TF:

```bash
ros2 run tf2_ros tf2_echo odom base_link
```

Check command subscription:

```bash
ros2 topic info /cmd_vel -v
```

Expected:

```text
Subscriber:
  /base_driver
```

---

# 6. Verify Robot Data on the PC

Open a terminal on the PC:

```bash
source /opt/ros/jazzy/setup.bash

if [ -f ~/workspace/ros2_ws/install/setup.bash ]; then
  source ~/workspace/ros2_ws/install/setup.bash
fi

export ROS_DOMAIN_ID=42
unset ROS_LOCALHOST_ONLY
export ROS_AUTOMATIC_DISCOVERY_RANGE=SUBNET
```

Restart the ROS daemon:

```bash
ros2 daemon stop
sleep 2
ros2 daemon start
sleep 2
```

Check nodes:

```bash
ros2 node list
```

Check odometry:

```bash
ros2 topic hz /odom
```

Check TF:

```bash
ros2 run tf2_ros tf2_echo odom base_link
```

Do not continue until the PC receives `/odom` and `odom -> base_link`.

---

# 7. Start RViz2 on the PC

```bash
source /opt/ros/jazzy/setup.bash

if [ -f ~/workspace/ros2_ws/install/setup.bash ]; then
  source ~/workspace/ros2_ws/install/setup.bash
fi

export ROS_DOMAIN_ID=42
unset ROS_LOCALHOST_ONLY
export ROS_AUTOMATIC_DISCOVERY_RANGE=SUBNET

rviz2
```

Set:

```text
Fixed Frame: odom
```

Add these displays:

```text
Grid
RobotModel
TF
Odometry
```

Configure:

```text
Odometry topic: /odom
```

Recommended grid settings:

```text
Plane: XY
Cell Size: 1.0
Plane Cell Count: 20
```

The robot should appear on the grid and move according to odometry.

---

## RobotModel troubleshooting

If RobotModel reports that the robot description is missing:

```bash
ros2 topic echo /robot_description --once
```

If the topic is unavailable, run `robot_state_publisher` locally on the PC using the same URDF package, or verify that it is publishing from the Rock 5C.

Check TF:

```bash
ros2 run tf2_ros tf2_echo odom base_link
```

The RobotModel cannot be displayed correctly without the required link transforms.

---

# 8. Control the Robot from the PC Keyboard

Open a new PC terminal:

```bash
source /opt/ros/jazzy/setup.bash

export ROS_DOMAIN_ID=42
unset ROS_LOCALHOST_ONLY
export ROS_AUTOMATIC_DISCOVERY_RANGE=SUBNET

ros2 run teleop_twist_keyboard teleop_twist_keyboard
```

The standard controls are:

```text
u    i    o
j    k    l
m    ,    .
```

Common commands:

```text
i = forward
, = backward
j = rotate left
l = rotate right
k = stop
```

Speed controls:

```text
q/z = increase/decrease all speeds
w/x = increase/decrease linear speed
e/c = increase/decrease angular speed
```

Start with low speeds.

Recommended initial values:

```text
Linear speed:  0.10 m/s
Angular speed: 0.25 rad/s
```

The terminal running `teleop_twist_keyboard` must remain focused for keyboard input.

---

# 9. Safety Check Before Driving

Before placing the robot on the floor:

1. Lift the drive wheels off the ground.
2. Press `i` and confirm both wheels drive forward.
3. Press `,` and confirm both wheels reverse.
4. Press `j` and confirm the robot would rotate left.
5. Press `l` and confirm the robot would rotate right.
6. Press `k` and confirm the motors stop.
7. Confirm the STM32 watchdog stops the robot if `/cmd_vel` disappears.

Stop immediately if the wheel direction is incorrect.

---

# 10. Final Run Commands

## Rock 5C

```bash
source ~/ros2_humble/install/setup.bash
source ~/workspace/ros2_ws/install/setup.bash

export ROS_DOMAIN_ID=42
unset ROS_LOCALHOST_ONLY
export ROS_AUTOMATIC_DISCOVERY_RANGE=SUBNET

ros2 launch ros_car_bringup base.launch.py
```

## PC terminal P1 — RViz2

```bash
source /opt/ros/jazzy/setup.bash
source ~/workspace/ros2_ws/install/setup.bash

export ROS_DOMAIN_ID=42
unset ROS_LOCALHOST_ONLY
export ROS_AUTOMATIC_DISCOVERY_RANGE=SUBNET

rviz2
```

RViz settings:

```text
Fixed Frame: odom

Displays:
Grid
RobotModel
TF
Odometry (/odom)
```

## PC terminal P2 — keyboard control

```bash
source /opt/ros/jazzy/setup.bash

export ROS_DOMAIN_ID=42
unset ROS_LOCALHOST_ONLY
export ROS_AUTOMATIC_DISCOVERY_RANGE=SUBNET

ros2 run teleop_twist_keyboard teleop_twist_keyboard
```

---

# 11. Quick Verification Commands

On either machine:

```bash
ros2 topic hz /odom
```

```bash
ros2 run tf2_ros tf2_echo odom base_link
```

```bash
ros2 topic info /cmd_vel -v
```

```bash
ros2 topic echo /cmd_vel
```

Expected data flow:

```text
PC keyboard
    ↓
teleop_twist_keyboard
    ↓
/cmd_vel
    ↓ DDS
Rock 5C base_driver
    ↓
STM32
    ↓
motors

wheel feedback
    ↓
STM32
    ↓
Rock 5C base_driver
    ↓
/odom and odom -> base_link
    ↓ DDS
PC RViz2
```

---

# 12. Common Problems

## PC cannot see Rock nodes

Check both machines:

```bash
echo "$ROS_DOMAIN_ID"
echo "$ROS_AUTOMATIC_DISCOVERY_RANGE"
```

Expected:

```text
42
SUBNET
```

Restart the PC daemon:

```bash
ros2 daemon stop
sleep 2
ros2 daemon start
```

Check network access:

```bash
ping <ROCK_5C_IP>
```

---

## Keyboard command publishes but robot does not move

Check:

```bash
ros2 topic info /cmd_vel -v
```

The topic must have:

```text
Publisher:
  teleop_twist_keyboard

Subscriber:
  base_driver
```

Observe commands:

```bash
ros2 topic echo /cmd_vel
```

Then check:

```text
serial port
STM32 connection
watchdog state
motor enable state
CAN connection
motor IDs
```

---

## Robot moves but RViz does not move

Check odometry:

```bash
ros2 topic hz /odom
ros2 topic echo /odom
```

Check TF:

```bash
ros2 run tf2_ros tf2_echo odom base_link
```

Publishing `/odom` alone is not enough. The base driver must also publish:

```text
odom -> base_link
```

---

## RobotModel is missing

Check:

```bash
ros2 topic echo /robot_description --once
```

Check required transforms:

```bash
ros2 topic echo /tf --once
ros2 topic echo /tf_static --once
```

Verify that `robot_state_publisher` is running.

---

## RViz says `map` does not exist

This demo does not use a map.

Use:

```text
Fixed Frame: odom
```

Do not use:

```text
Fixed Frame: map
```

---

# 13. Demo Checklist

```text
[ ] Rock bringup starts
[ ] base_driver is running
[ ] robot_state_publisher is running
[ ] PC receives /odom
[ ] PC receives odom -> base_link
[ ] RViz Fixed Frame is odom
[ ] Grid is visible
[ ] RobotModel is visible
[ ] Odometry display is visible
[ ] keyboard terminal publishes /cmd_vel
[ ] robot moves forward and backward
[ ] robot rotates left and right
[ ] k stops the robot
[ ] RViz movement matches physical movement
```

Suggested video sequence:

1. Show the physical robot.
2. Start the Rock 5C bringup.
3. Start RViz2 on the PC.
4. Show the robot model on the grid.
5. Start keyboard teleoperation.
6. Drive forward and backward.
7. Rotate left and right.
8. Show the physical car and RViz moving together.
9. Stop the robot with `k`.

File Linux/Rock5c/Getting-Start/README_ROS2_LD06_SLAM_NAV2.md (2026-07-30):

# ROS 2 Distributed Mobile Robot: LD06 SLAM and Nav2

This project runs a differential-drive robot as a distributed ROS 2 system.

- **Rock 5C / ROS 2 Humble** runs the hardware-facing robot stack.
- **Ubuntu PC / ROS 2 Jazzy** runs SLAM Toolbox, Nav2, and RViz2.
- The LD06 publishes `/scan`.
- The robot base publishes `/odom` and `odom -> base_link`.
- The PC builds the map and sends velocity commands back through `/cmd_vel`.

> This README is written so that a new user can clone the repository, install dependencies, build the workspace, launch the robot, create a map, and test navigation.

---

## 1. System Architecture

```text
┌───────────────────────────────┐
│ Rock 5C — ROS 2 Humble        │
│                               │
│ ros_car_base                  │
│   └── base_driver             │
│                               │
│ ros_car_description           │
│   └── robot_state_publisher   │
│                               │
│ LD06 driver                   │
│   └── publishes /scan         │
│                               │
│ TF publishers                 │
│   ├── odom -> base_link       │
│   └── base_link -> laser_frame│
│                               │
│ subscribes /cmd_vel           │
└───────────────┬───────────────┘
                │
                │ ROS 2 DDS over LAN
                │ ROS_DOMAIN_ID=42
                │
┌───────────────▼───────────────┐
│ Ubuntu PC — ROS 2 Jazzy       │
│                               │
│ SLAM Toolbox                  │
│   └── map -> odom             │
│                               │
│ Nav2                          │
│   └── publishes /cmd_vel      │
│                               │
│ RViz2                         │
│   └── visualization           │
└───────────────────────────────┘
```

Final TF tree:

```text
map
└── odom
    └── base_link
        ├── laser_frame
        ├── left_wheel_link
        └── right_wheel_link
```

Frame ownership:

| Transform | Publisher |
|---|---|
| `map -> odom` | SLAM Toolbox on the PC |
| `odom -> base_link` | `base_driver` on the Rock 5C |
| `base_link -> laser_frame` | robot description or static TF publisher |
| wheel transforms | `robot_state_publisher` |

---

## 2. Hardware and Software

### Robot computer

- Radxa Rock 5C
- Debian 12
- ROS 2 Humble workspace built from source
- STM32 motor controller
- Two CAN FOC motors
- LD06 2D LiDAR

### Workstation

- Ubuntu 24.04
- ROS 2 Jazzy
- RViz2
- SLAM Toolbox
- Navigation2

### Current robot geometry

```text
Wheel diameter:   0.062 m
Wheel separation: 0.122 m
```

LD06 transform:

```text
Parent frame: base_link
Child frame:  laser_frame

x:    -0.007 m
y:     0.000 m
z:     0.125 m
roll:  0.000 rad
pitch: 0.000 rad
yaw:   0.000 rad
```

---

## 3. Repository Structure

The repository should contain the following ROS 2 packages:

```text
ros2_ws/
├── src/
│   ├── ros_car_base/
│   ├── ros_car_description/
│   ├── ros_car_bringup/
│   ├── ros_car_slam/
│   └── ldlidar/
├── build/
├── install/
└── log/
```

Recommended package responsibilities:

```text
ros_car_base
└── serial/CAN base driver, odometry, /cmd_vel handling

ros_car_description
└── URDF/Xacro, robot geometry, wheel links, sensor links

ros_car_bringup
└── Rock-side launch files for base, description, TF, and LD06

ros_car_slam
└── PC-side SLAM parameters, Nav2 parameters, RViz config, maps

ldlidar
└── LD06 hardware driver
```

The final Rock-side launch command in this README assumes this launch file exists:

```text
ros_car_bringup/launch/robot.launch.py
```

It should start:

```text
base_driver
robot_state_publisher
LD06 driver
base_link -> laser_frame transform
```

---

# Part A — Clone and Build the Rock 5C Workspace

## 4. Install build tools on the Rock 5C

```bash
sudo apt update

sudo apt install -y \
  git \
  python3-pip \
  python3-rosdep \
  python3-colcon-common-extensions
```

Initialize `rosdep` if needed:

```bash
sudo rosdep init
rosdep update
```

If `sudo rosdep init` reports that the sources already exist, continue with:

```bash
rosdep update
```

## 5. Clone the repository

```bash
mkdir -p ~/workspace
cd ~/workspace

git clone <YOUR_GITHUB_REPOSITORY_URL> ros2_ws
cd ~/workspace/ros2_ws
```

Expected repository root:

```text
src
README.md
```

## 6. Source ROS 2 Humble on Rock 5C

```bash
source ~/ros2_humble/install/setup.bash
```

Verify:

```bash
printenv ROS_DISTRO
```

Expected:

```text
humble
```

## 7. Install dependencies

```bash
cd ~/workspace/ros2_ws

rosdep install \
  --from-paths src \
  --ignore-src \
  --rosdistro humble \
  -r \
  -y
```

## 8. Build the Rock workspace

```bash
cd ~/workspace/ros2_ws

source ~/ros2_humble/install/setup.bash

colcon build --symlink-install
```

Source the overlay:

```bash
source ~/workspace/ros2_ws/install/setup.bash
```

Verify packages:

```bash
ros2 pkg list | grep -E \
'ros_car_base|ros_car_description|ros_car_bringup|ldlidar'
```

## 9. Configure hardware permissions

Current project examples:

```text
Base controller: /dev/ttyS4
LD06:            /dev/ttyS6
```

Check devices:

```bash
ls -l /dev/ttyS*
ls -l /dev/ttyUSB*
ls -l /dev/ttyACM*
```

Add the user to `dialout`:

```bash
sudo usermod -aG dialout "$USER"
```

Log out and log back in.

Temporary permission test only:

```bash
sudo chmod 666 /dev/ttyS4
sudo chmod 666 /dev/ttyS6
```

Use a `udev` rule for a permanent deployment.

---

# Part B — Configure ROS 2 Networking

## 10. Put both machines on the same network

Rock 5C:

```bash
hostname -I
```

PC:

```bash
ping <ROCK_5C_IP>
```

## 11. Use the same ROS domain

Run on both machines:

```bash
export ROS_DOMAIN_ID=42
unset ROS_LOCALHOST_ONLY
export ROS_AUTOMATIC_DISCOVERY_RANGE=SUBNET
```

Optional persistent configuration:

```bash
cat >> ~/.bashrc <<'EOF2'

# ROS 2 distributed robot network
export ROS_DOMAIN_ID=42
unset ROS_LOCALHOST_ONLY
export ROS_AUTOMATIC_DISCOVERY_RANGE=SUBNET
EOF2
```

Reload:

```bash
source ~/.bashrc
```

Verify:

```bash
echo "$ROS_DOMAIN_ID"
echo "$ROS_AUTOMATIC_DISCOVERY_RANGE"
```

Expected:

```text
42
SUBNET
```

---

# Part C — Start the Robot on Rock 5C

## 12. Start the complete Rock bringup

```bash
source ~/ros2_humble/install/setup.bash
source ~/workspace/ros2_ws/install/setup.bash

export ROS_DOMAIN_ID=42
unset ROS_LOCALHOST_ONLY
export ROS_AUTOMATIC_DISCOVERY_RANGE=SUBNET

ros2 launch ros_car_bringup robot.launch.py
```

This bringup should start:

```text
/base_driver
/robot_state_publisher
/ldlidar
/static_transform_publisher
```

Expected topics:

```text
/cmd_vel
/odom
/scan
/tf
/tf_static
/robot_description
/joint_states
```

## 13. Manual fallback

Use this only until `robot.launch.py` is complete.

### Terminal R1 — base driver

```bash
source ~/ros2_humble/install/setup.bash
source ~/workspace/ros2_ws/install/setup.bash

export ROS_DOMAIN_ID=42
unset ROS_LOCALHOST_ONLY
export ROS_AUTOMATIC_DISCOVERY_RANGE=SUBNET

ros2 run ros_car_base base_driver
```

Find the real executable if needed:

```bash
ros2 pkg executables ros_car_base
```

### Terminal R2 — robot description

```bash
source ~/ros2_humble/install/setup.bash
source ~/workspace/ros2_ws/install/setup.bash

export ROS_DOMAIN_ID=42
unset ROS_LOCALHOST_ONLY
export ROS_AUTOMATIC_DISCOVERY_RANGE=SUBNET

ros2 launch ros_car_description display.launch.py
```

If the launch name differs:

```bash
find ~/workspace/ros2_ws/src/ros_car_description -maxdepth 3 -type f
```

### Terminal R3 — LD06

```bash
source ~/ros2_humble/install/setup.bash
source ~/workspace/ros2_ws/install/setup.bash

export ROS_DOMAIN_ID=42
unset ROS_LOCALHOST_ONLY
export ROS_AUTOMATIC_DISCOVERY_RANGE=SUBNET

ros2 launch ldlidar ldlidar.launch.py \
  serial_port:=/dev/ttyS6 \
  lidar_frame:=laser_frame \
  topic_name:=scan
```

### Terminal R4 — temporary LD06 TF

Use only if the transform is not already in the URDF or bringup launch:

```bash
source ~/ros2_humble/install/setup.bash
source ~/workspace/ros2_ws/install/setup.bash

export ROS_DOMAIN_ID=42
unset ROS_LOCALHOST_ONLY
export ROS_AUTOMATIC_DISCOVERY_RANGE=SUBNET

ros2 run tf2_ros static_transform_publisher \
  --x -0.007 \
  --y 0.0 \
  --z 0.125 \
  --roll 0.0 \
  --pitch 0.0 \
  --yaw 0.0 \
  --frame-id base_link \
  --child-frame-id laser_frame
```

Do not publish the same transform twice.

## 14. Verify the Rock-side stack

```bash
source ~/ros2_humble/install/setup.bash
source ~/workspace/ros2_ws/install/setup.bash

export ROS_DOMAIN_ID=42
unset ROS_LOCALHOST_ONLY
export ROS_AUTOMATIC_DISCOVERY_RANGE=SUBNET
```

Nodes:

```bash
ros2 node list
```

LiDAR rate:

```bash
ros2 topic hz /scan
```

Expected: approximately `10 Hz`.

Odometry rate:

```bash
ros2 topic hz /odom
```

Expected: approximately `44 Hz`.

Complete TF:

```bash
ros2 run tf2_ros tf2_echo odom laser_frame
```

Expected chain:

```text
odom -> base_link -> laser_frame
```

An initial missing-frame warning can occur during discovery. Valid transforms must appear shortly afterwards.

---

# Part D — Prepare the Ubuntu PC

## 15. Install PC dependencies

```bash
sudo apt update

sudo apt install -y \
  ros-jazzy-rviz2 \
  ros-jazzy-slam-toolbox \
  ros-jazzy-navigation2 \
  ros-jazzy-nav2-bringup
```

## 16. Clone and build the PC workspace

```bash
mkdir -p ~/workspace
cd ~/workspace

git clone <YOUR_GITHUB_REPOSITORY_URL> ros2_ws
cd ~/workspace/ros2_ws
```

Install dependencies:

```bash
source /opt/ros/jazzy/setup.bash

rosdep install \
  --from-paths src \
  --ignore-src \
  --rosdistro jazzy \
  -r \
  -y
```

Build workstation packages:

```bash
colcon build \
  --symlink-install \
  --packages-select \
  ros_car_description \
  ros_car_slam
```

Source:

```bash
source ~/workspace/ros2_ws/install/setup.bash
```

If every package supports Jazzy:

```bash
colcon build --symlink-install
```

## 17. Verify Rock data on the PC

```bash
source /opt/ros/jazzy/setup.bash

if [ -f ~/workspace/ros2_ws/install/setup.bash ]; then
  source ~/workspace/ros2_ws/install/setup.bash
fi

export ROS_DOMAIN_ID=42
unset ROS_LOCALHOST_ONLY
export ROS_AUTOMATIC_DISCOVERY_RANGE=SUBNET
```

Restart the daemon under the correct domain:

```bash
ros2 daemon stop
sleep 2
ros2 daemon start
sleep 2
```

Check:

```bash
ros2 node list
ros2 topic hz /scan
ros2 topic hz /odom
ros2 run tf2_ros tf2_echo odom laser_frame
```

Do not start SLAM until these pass:

```text
/scan: approximately 10 Hz
/odom: approximately 44 Hz
odom -> laser_frame: available
```

---

# Part E — Configure and Run SLAM Toolbox

## 18. SLAM parameters

Expected path:

```text
ros_car_slam/config/slam_params.yaml
```

Recommended baseline:

```yaml
slam_toolbox:
  ros__parameters:
    solver_plugin: solver_plugins::CeresSolver
    ceres_linear_solver: SPARSE_NORMAL_CHOLESKY
    ceres_preconditioner: SCHUR_JACOBI
    ceres_trust_strategy: LEVENBERG_MARQUARDT
    ceres_dogleg_type: TRADITIONAL_DOGLEG
    ceres_loss_function: None

    odom_frame: odom
    map_frame: map
    base_frame: base_link
    scan_topic: /scan

    mode: mapping
    use_sim_time: false

    use_map_saver: true
    debug_logging: false
    throttle_scans: 1

    transform_publish_period: 0.05
    map_update_interval: 1.0
    resolution: 0.05

    min_laser_range: 0.05
    max_laser_range: 12.0

    minimum_time_interval: 0.10
    transform_timeout: 0.5
    tf_buffer_duration: 30.0

    stack_size_to_use: 40000000
    enable_interactive_mode: true

    use_scan_matching: true
    use_scan_barycenter: true

    minimum_travel_distance: 0.05
    minimum_travel_heading: 0.05

    scan_buffer_size: 10
    scan_buffer_maximum_scan_distance: 10.0

    link_match_minimum_response_fine: 0.1
    link_scan_maximum_distance: 1.5

    loop_search_maximum_distance: 3.0
    do_loop_closing: true
    loop_match_minimum_chain_size: 10
    loop_match_maximum_variance_coarse: 3.0
    loop_match_minimum_response_coarse: 0.35
    loop_match_minimum_response_fine: 0.45

    correlation_search_space_dimension: 0.5
    correlation_search_space_resolution: 0.01
    correlation_search_space_smear_deviation: 0.1

    loop_search_space_dimension: 8.0
    loop_search_space_resolution: 0.05
    loop_search_space_smear_deviation: 0.03

    distance_variance_penalty: 0.5
    angle_variance_penalty: 1.0

    fine_search_angle_offset: 0.00349
    coarse_search_angle_offset: 0.349
    coarse_angle_resolution: 0.0349

    minimum_angle_penalty: 0.9
    minimum_distance_penalty: 0.5

    use_response_expansion: true
```

## 19. Start SLAM Toolbox

Preferred repository launch:

```bash
source /opt/ros/jazzy/setup.bash
source ~/workspace/ros2_ws/install/setup.bash

export ROS_DOMAIN_ID=42
unset ROS_LOCALHOST_ONLY
export ROS_AUTOMATIC_DISCOVERY_RANGE=SUBNET

ros2 launch ros_car_slam slam.launch.py
```

Direct fallback:

```bash
source /opt/ros/jazzy/setup.bash

export ROS_DOMAIN_ID=42
unset ROS_LOCALHOST_ONLY
export ROS_AUTOMATIC_DISCOVERY_RANGE=SUBNET

ros2 launch slam_toolbox online_async_launch.py \
  use_sim_time:=false \
  slam_params_file:=$HOME/workspace/ros2_ws/src/ros_car_slam/config/slam_params.yaml
```

## 20. Verify SLAM

```bash
source /opt/ros/jazzy/setup.bash
source ~/workspace/ros2_ws/install/setup.bash

export ROS_DOMAIN_ID=42
unset ROS_LOCALHOST_ONLY
export ROS_AUTOMATIC_DISCOVERY_RANGE=SUBNET
```

Check subscription:

```bash
ros2 topic info /scan -v
```

Check map:

```bash
ros2 topic hz /map
```

Check SLAM TF:

```bash
ros2 run tf2_ros tf2_echo map odom
```

SLAM is operational only when:

```text
map -> odom exists
/map publishes
```

---

# Part F — Run RViz2

## 21. Start RViz2

Preferred project config:

```bash
source /opt/ros/jazzy/setup.bash
source ~/workspace/ros2_ws/install/setup.bash

export ROS_DOMAIN_ID=42
unset ROS_LOCALHOST_ONLY
export ROS_AUTOMATIC_DISCOVERY_RANGE=SUBNET

rviz2 \
  -d ~/workspace/ros2_ws/src/ros_car_slam/rviz/mapping.rviz
```

Generic startup:

```bash
rviz2
```

Set:

```text
Fixed Frame: map
```

Add:

| Display | Topic |
|---|---|
| Map | `/map` |
| LaserScan | `/scan` |
| Odometry | `/odom` |
| RobotModel | `/robot_description` |
| TF | no topic selection required |

If `map` does not exist yet, temporarily set:

```text
Fixed Frame: odom
```

Switch back to `map` after `map -> odom` appears.

---

# Part G — Build a Map

## 22. Recommended speeds

```text
Linear speed:  0.10–0.15 m/s
Angular speed: 0.20–0.30 rad/s
```

## 23. Recommended mapping route

1. Start all nodes.
2. Keep the robot stationary for 5–10 seconds.
3. Drive forward slowly.
4. Avoid sudden acceleration.
5. Rotate slowly.
6. Follow room boundaries.
7. Avoid repeatedly spinning in place.
8. Return close to the starting position.
9. Continue slowly until loop closure corrects drift.
10. Stop before saving.

Avoid:

```text
fast rotation
wheel slip
collisions
lifting the robot
driving over cables
rapid forward/reverse changes
moving people near the LiDAR
```

---

# Part H — Rebuild an Unsatisfactory Map

## 24. Start a clean mapping session

Stop SLAM Toolbox:

```text
Ctrl+C
```

Restart it:

```bash
source /opt/ros/jazzy/setup.bash
source ~/workspace/ros2_ws/install/setup.bash

export ROS_DOMAIN_ID=42
unset ROS_LOCALHOST_ONLY
export ROS_AUTOMATIC_DISCOVERY_RANGE=SUBNET

ros2 launch ros_car_slam slam.launch.py
```

Or use the direct command:

```bash
ros2 launch slam_toolbox online_async_launch.py \
  use_sim_time:=false \
  slam_params_file:=$HOME/workspace/ros2_ws/src/ros_car_slam/config/slam_params.yaml
```

A fresh process starts a new empty map. RViz may display the old map briefly until new `/map` messages arrive.

## 25. Delete an old saved map

```bash
rm -f ~/workspace/ros2_ws/src/ros_car_slam/maps/room_map.*
```

## 26. Keep multiple attempts

```text
room_map_01
room_map_02
room_map_03
```

This prevents a new test from overwriting a good map.

---

# Part I — Save the Final Map

## 27. Save the map

```bash
mkdir -p ~/workspace/ros2_ws/src/ros_car_slam/maps
```

```bash
source /opt/ros/jazzy/setup.bash
source ~/workspace/ros2_ws/install/setup.bash

export ROS_DOMAIN_ID=42
unset ROS_LOCALHOST_ONLY
export ROS_AUTOMATIC_DISCOVERY_RANGE=SUBNET

ros2 run nav2_map_server map_saver_cli \
  -f ~/workspace/ros2_ws/src/ros_car_slam/maps/room_map
```

Expected files:

```text
room_map.yaml
room_map.pgm
```

Commit:

```bash
cd ~/workspace/ros2_ws

git add src/ros_car_slam/maps/
git commit -m "Add LD06 indoor occupancy map"
git push
```

---

# Part J — Start Nav2 While Mapping

## 28. Safety before Nav2

1. Confirm the base watchdog works.
2. Confirm stale `/cmd_vel` commands stop the motors.
3. Raise the wheels off the ground.
4. Test linear and angular directions.
5. Keep an emergency stop available.
6. Start with a target less than 0.5 m away.

## 29. Start Nav2

Preferred project launch:

```bash
source /opt/ros/jazzy/setup.bash
source ~/workspace/ros2_ws/install/setup.bash

export ROS_DOMAIN_ID=42
unset ROS_LOCALHOST_ONLY
export ROS_AUTOMATIC_DISCOVERY_RANGE=SUBNET

ros2 launch ros_car_slam navigation.launch.py
```

Direct fallback:

```bash
source /opt/ros/jazzy/setup.bash

export ROS_DOMAIN_ID=42
unset ROS_LOCALHOST_ONLY
export ROS_AUTOMATIC_DISCOVERY_RANGE=SUBNET

ros2 launch nav2_bringup navigation_launch.py \
  use_sim_time:=false \
  autostart:=true
```

The fallback uses Nav2 defaults. A physical robot should use a tuned project-specific parameter file with the correct footprint, speed limits, controller, planner, and costmap settings.

## 30. Verify `/cmd_vel`

```bash
ros2 topic info /cmd_vel -v
```

Expected:

```text
Publisher: Nav2 controller server
Subscriber: Rock 5C base_driver
```

Observe commands:

```bash
ros2 topic echo /cmd_vel
```

Check nodes:

```bash
ros2 node list | grep -E \
'planner|controller|behavior|bt_navigator|costmap|lifecycle'
```

## 31. Send a goal

In RViz:

1. Confirm `Fixed Frame = map`.
2. Select **Nav2 Goal**.
3. Click close to the robot.
4. Drag to set heading.
5. Observe global and local paths.
6. Be ready to stop the robot.

Command path:

```text
RViz Nav2 Goal
    ↓
BT Navigator
    ↓
Planner Server
    ↓
Controller Server
    ↓
/cmd_vel
    ↓
Rock 5C base_driver
    ↓
STM32
    ↓
motor controllers
```

---

# Part K — Final Startup Order

## Rock 5C

```bash
source ~/ros2_humble/install/setup.bash
source ~/workspace/ros2_ws/install/setup.bash

export ROS_DOMAIN_ID=42
unset ROS_LOCALHOST_ONLY
export ROS_AUTOMATIC_DISCOVERY_RANGE=SUBNET

ros2 launch ros_car_bringup robot.launch.py
```

Verify:

```bash
ros2 topic hz /scan
ros2 topic hz /odom
ros2 run tf2_ros tf2_echo odom laser_frame
```

## PC terminal P1 — SLAM

```bash
source /opt/ros/jazzy/setup.bash
source ~/workspace/ros2_ws/install/setup.bash

export ROS_DOMAIN_ID=42
unset ROS_LOCALHOST_ONLY
export ROS_AUTOMATIC_DISCOVERY_RANGE=SUBNET

ros2 launch ros_car_slam slam.launch.py
```

## PC terminal P2 — RViz

```bash
source /opt/ros/jazzy/setup.bash
source ~/workspace/ros2_ws/install/setup.bash

export ROS_DOMAIN_ID=42
unset ROS_LOCALHOST_ONLY
export ROS_AUTOMATIC_DISCOVERY_RANGE=SUBNET

rviz2 \
  -d ~/workspace/ros2_ws/src/ros_car_slam/rviz/mapping.rviz
```

## PC terminal P3 — Nav2

Start only after SLAM is healthy:

```bash
source /opt/ros/jazzy/setup.bash
source ~/workspace/ros2_ws/install/setup.bash

export ROS_DOMAIN_ID=42
unset ROS_LOCALHOST_ONLY
export ROS_AUTOMATIC_DISCOVERY_RANGE=SUBNET

ros2 launch ros_car_slam navigation.launch.py
```

---

# Part L — Troubleshooting

## PC receives no Rock topics

```bash
echo "$ROS_DOMAIN_ID"
echo "$ROS_AUTOMATIC_DISCOVERY_RANGE"
```

Expected:

```text
42
SUBNET
```

Restart daemon:

```bash
ros2 daemon stop
sleep 2
ros2 daemon start
```

Check connectivity:

```bash
ping <OTHER_MACHINE_IP>
```

Multicast test:

Machine A:

```bash
ros2 multicast receive
```

Machine B:

```bash
ros2 multicast send
```

## `/scan` exists but RViz shows no laser

```bash
ros2 topic echo /scan --once
```

Confirm:

```text
header.frame_id: laser_frame
```

Check TF:

```bash
ros2 run tf2_ros tf2_echo odom laser_frame
```

RViz:

```text
Fixed Frame: odom
LaserScan topic: /scan
```

## `/odom` exists but TF does not

An odometry topic does not automatically create TF. The base driver must publish:

```text
odom -> base_link
```

Check:

```bash
ros2 run tf2_ros tf2_echo odom base_link
```

## `map` frame does not exist

Check:

```bash
ros2 topic hz /scan
ros2 run tf2_ros tf2_echo odom laser_frame
ros2 topic info /scan -v
```

Inspect SLAM logs for:

```text
Message Filter dropping message
Failed to compute laser pose
Extrapolation Error
```

Verify:

```yaml
odom_frame: odom
map_frame: map
base_frame: base_link
scan_topic: /scan
```

## Walls appear doubled

Common causes:

```text
wheel slip
incorrect wheel separation
incorrect wheel diameter
fast rotation
rapid acceleration
incorrect LiDAR yaw
moving objects
poor loop closure
```

Action:

1. Restart SLAM.
2. Move more slowly.
3. Reduce angular speed.
4. Verify wheel geometry.
5. Verify `base_link -> laser_frame`.
6. Repeat the route.

## Map is slightly rotated

This can be normal. The map axes are initialized from the robot pose when SLAM starts. A rotated room outline does not necessarily indicate an error.

A progressively bending or duplicated map is not normal and usually indicates odometry, TF, motion, or scan-matching problems.

## Robot moves in the wrong direction

Stop immediately.

```bash
ros2 topic echo /cmd_vel
```

For positive `linear.x`, the chassis must move forward.

For positive `angular.z`, the chassis must rotate counterclockwise under the ROS coordinate convention.

Correct motor signs before using Nav2.

---

# Part M — Demonstration Checklist

```text
[ ] Rock bringup starts with one command
[ ] /scan is stable at approximately 10 Hz
[ ] /odom is stable at approximately 44 Hz
[ ] odom -> laser_frame is available
[ ] PC receives Rock topics
[ ] SLAM produces /map
[ ] map -> odom is available
[ ] RViz shows robot, laser, map, and TF
[ ] robot can be driven slowly for mapping
[ ] loop closure is visible
[ ] final map is saved
[ ] Nav2 publishes /cmd_vel
[ ] short Nav2 goal succeeds safely
[ ] emergency stop is available
```

Suggested video sequence:

1. Show the physical robot.
2. Start Rock bringup.
3. Show `/scan` and `/odom` rates.
4. Show the TF tree.
5. Start SLAM on the PC.
6. Show live LD06 scans in RViz.
7. Drive around the room.
8. Show loop closure.
9. Save the map.
10. Send a short Nav2 goal.
11. Show the architecture diagram.

---

# References

- ROS 2 workspace and `colcon`:  
  https://docs.ros.org/en/jazzy/Tutorials/Beginner-Client-Libraries/Colcon-Tutorial.html

- ROS 2 dependency management with `rosdep`:  
  https://docs.ros.org/en/jazzy/Tutorials/Intermediate/Rosdep.html

- Nav2 navigating while mapping:  
  https://docs.nav2.org/tutorials/docs/navigation2_with_slam.html

- Nav2 mapping and localization:  
  https://docs.nav2.org/setup_guides/sensors/mapping_localization.html

- Nav2 footprint configuration:  
  https://docs.nav2.org/setup_guides/footprint/setup_footprint.html

---

## Current Project Status

Validated:

```text
Rock /scan: approximately 10 Hz
Rock /odom: approximately 44 Hz
Rock odom -> laser_frame: working

PC /scan: received
PC /odom: received
PC odom -> laser_frame: received

SLAM Toolbox: mapping operational
RViz2: map visualization operational
```

Still required before calling the repository complete:

```text
Create and validate ros_car_bringup/launch/robot.launch.py
Create and validate ros_car_slam/launch/slam.launch.py
Create and tune project-specific Nav2 parameters
Create the correct robot footprint
Store the RViz configuration in the repository
Document the emergency-stop procedure
```

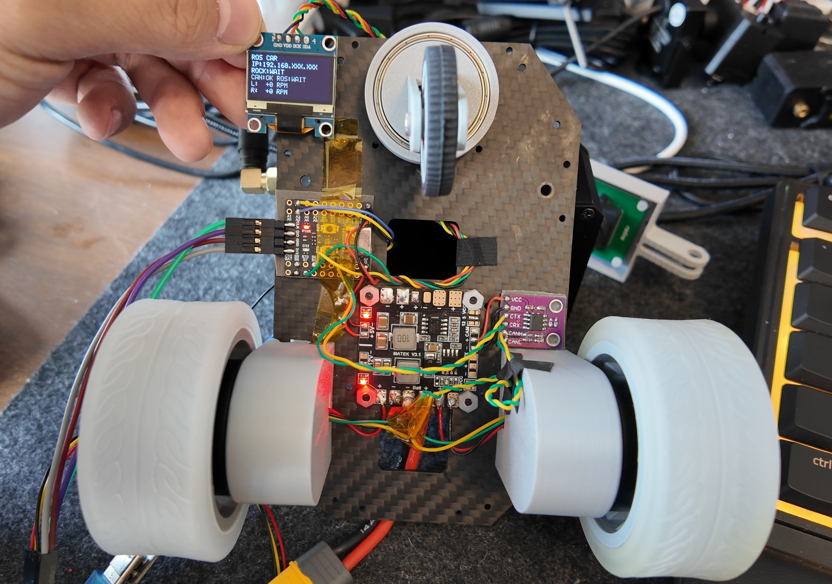
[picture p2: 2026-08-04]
Images/base.jpg

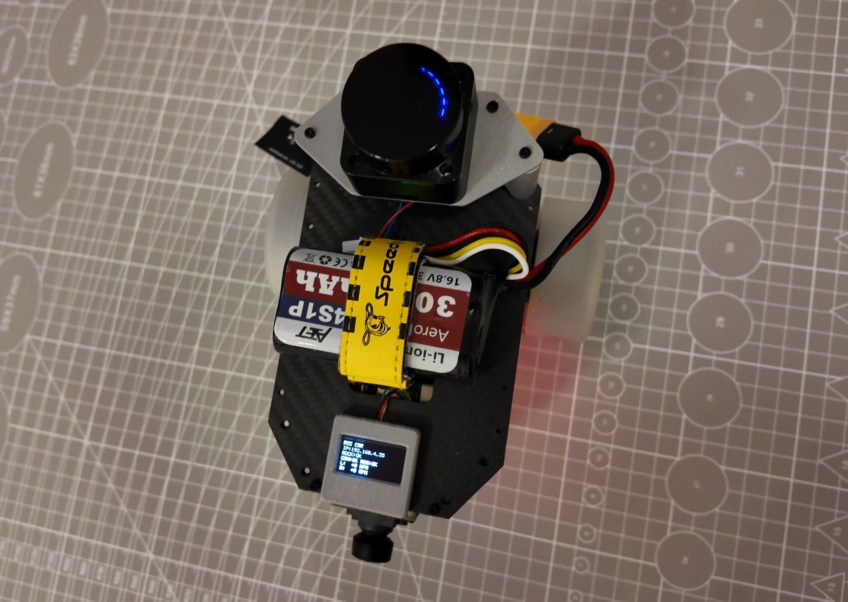
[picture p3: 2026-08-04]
Images/top.jpg

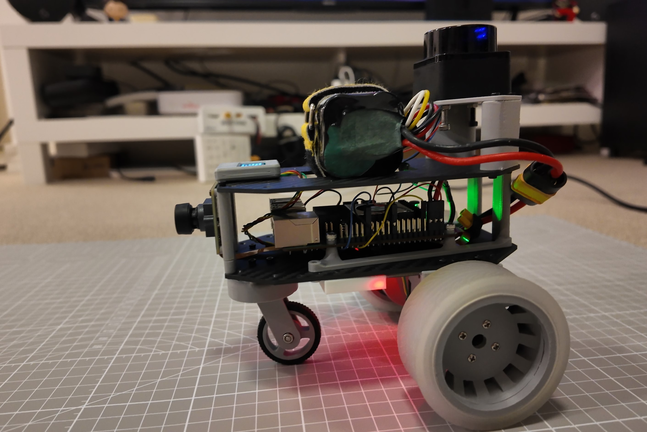
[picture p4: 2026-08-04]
Images/side-1.jpg

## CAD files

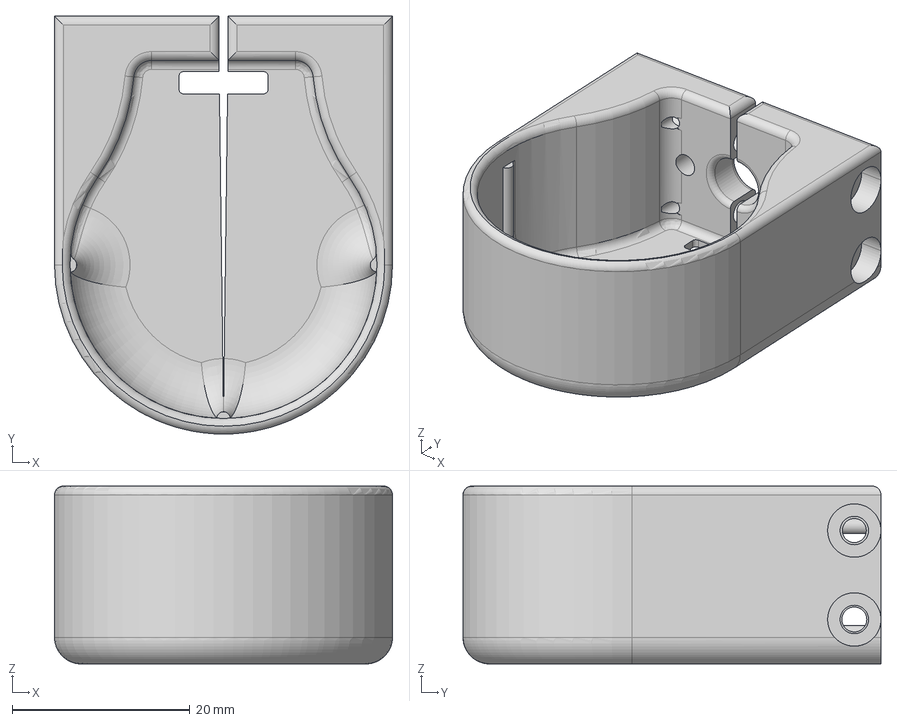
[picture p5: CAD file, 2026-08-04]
3D model/base.step
38.0 x 47.0 x 20.0 mm

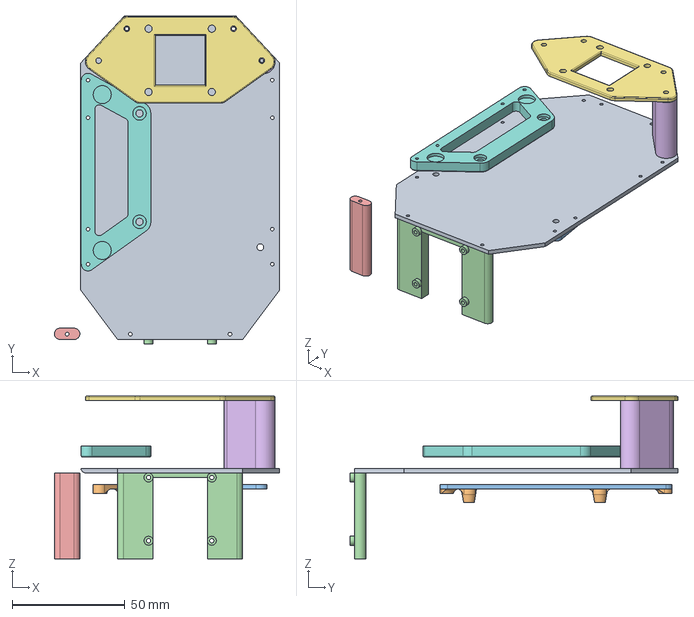
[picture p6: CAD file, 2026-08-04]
3D model/base-2.step
99.7 x 145.2 x 72.0 mm

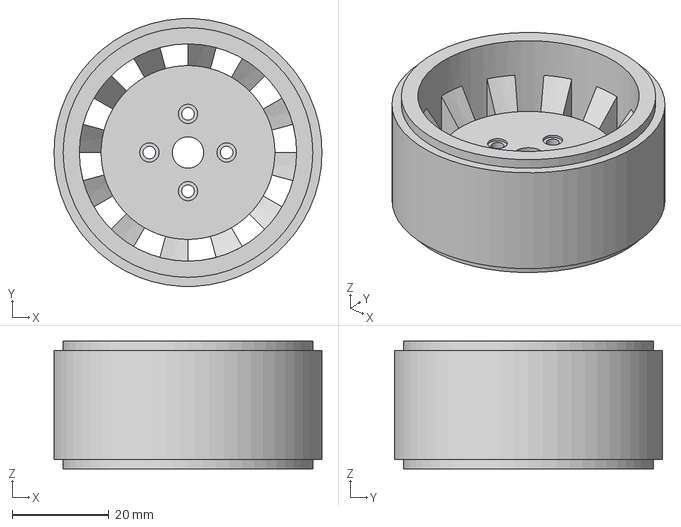
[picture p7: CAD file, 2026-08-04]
3D model/tyre.step
55.5 x 55.4 x 26.5 mm

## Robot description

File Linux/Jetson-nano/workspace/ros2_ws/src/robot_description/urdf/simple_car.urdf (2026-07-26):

<?xml version="1.0"?>

<robot name="simple_car">

  <!-- ======================= -->
  <!-- Base Link -->
  <!-- ======================= -->

  <link name="base_link">

    <visual>
      <origin xyz="0 0 0.05" rpy="0 0 0"/>

      <geometry>
        <box size="0.40 0.30 0.10"/>
      </geometry>
    </visual>

  </link>


  <!-- ======================= -->
  <!-- Left Wheel -->
  <!-- ======================= -->

  <link name="left_wheel_link">

    <visual>
      <geometry>
        <cylinder radius="0.05" length="0.03"/>
      </geometry>

      <origin xyz="0 0 0" rpy="1.5708 0 0" />

    </visual>

  </link>


  <joint name="left_wheel_joint" type="continuous" >

    <parent link="base_link"/>

    <child link="left_wheel_link"/>

    <origin xyz="0 0.165 0" rpy="0 0 0" />

    <axis xyz="0 1 0"/>

  </joint>


  <!-- ======================= -->
  <!-- Right Wheel -->
  <!-- ======================= -->

  <link name="right_wheel_link">

    <visual>

      <geometry>
        <cylinder radius="0.05" length="0.03"/>
      </geometry>

      <origin xyz="0 0 0" rpy="1.5708 0 0" />

    </visual>

  </link>


  <joint name="right_wheel_joint" type="continuous" >

    <parent link="base_link"/>

    <child link="right_wheel_link"/>

    <origin xyz="0 -0.165 0" rpy="0 0 0" />

    <axis xyz="0 1 0"/>

  </joint>


  <!-- ======================= -->
  <!-- Livox Mid-360 -->
  <!-- ======================= -->

  <link name="livox_frame">

    <visual>

      <geometry>
        <box size="0.08 0.08 0.06"/>
      </geometry>

      <origin xyz="0 0 0" rpy="0 0 0" />

    </visual>

  </link>


  <joint name="livox_joint" type="fixed" >

    <parent link="base_link"/>

    <child link="livox_frame"/>

    <origin xyz="0 0 0.18" rpy="0 0 0" />

  </joint>

</robot>

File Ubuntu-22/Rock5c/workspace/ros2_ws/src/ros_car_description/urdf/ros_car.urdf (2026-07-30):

<?xml version="1.0"?>

<robot name="ros_car">

  <!-- ========================================================= -->
  <!-- BASE                                                      -->
  <!-- ========================================================= -->

  <link name="base_link">

    <visual>
      <origin xyz="0 0 0" rpy="0 0 0"/>

      <geometry>
        <box size="0.180 0.100 0.035"/>
      </geometry>
    </visual>

  </link>


  <!-- ========================================================= -->
  <!-- LEFT WHEEL                                                -->
  <!-- ========================================================= -->

  <link name="left_wheel_link">

    <visual>
      <origin xyz="0 0 0" rpy="1.57079632679 0 0"/>

      <geometry>
        <cylinder radius="0.031" length="0.020"/>
      </geometry>
    </visual>

  </link>


  <joint name="left_wheel_joint" type="continuous">

    <parent link="base_link"/>

    <child link="left_wheel_link"/>

    <origin xyz="0 0.061 0" rpy="0 0 0"/>

    <axis xyz="0 1 0"/>

  </joint>


  <!-- ========================================================= -->
  <!-- RIGHT WHEEL                                               -->
  <!-- ========================================================= -->

  <link name="right_wheel_link">

    <visual>
      <origin xyz="0 0 0" rpy="1.57079632679 0 0"/>

      <geometry>
        <cylinder radius="0.031" length="0.020"/>
      </geometry>
    </visual>

  </link>


  <joint name="right_wheel_joint" type="continuous">

    <parent link="base_link"/>

    <child link="right_wheel_link"/>

    <origin xyz="0 -0.061 0" rpy="0 0 0"/>

    <axis xyz="0 1 0"/>

  </joint>


  <!-- ========================================================= -->
  <!-- LIDAR PLACEHOLDER                                         -->
  <!-- ========================================================= -->

  <link name="lidar_link"/>

  <joint name="lidar_joint" type="fixed">

    <parent link="base_link"/>
    <child link="lidar_link"/>

    <origin xyz="0.050 0 0.100" rpy="0 0 0"/>

  </joint>


  <!-- ========================================================= -->
  <!-- CAMERA PLACEHOLDER                                        -->
  <!-- ========================================================= -->

  <link name="camera_link"/>

  <joint name="camera_joint" type="fixed">

    <parent link="base_link"/>
    <child link="camera_link"/>

    <origin xyz="0.070 0 0.080" rpy="0 0 0"/>

  </joint>

</robot>

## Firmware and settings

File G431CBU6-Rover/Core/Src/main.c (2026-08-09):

#include "main.h"

#include <stdbool.h>
#include <stddef.h>
#include <stdint.h>
#include <string.h>

#include <geometry_msgs/msg/twist.h>
#include <rcl/rcl.h>
#include <rcl/time.h>
#include <rclc/executor.h>
#include <rclc/rclc.h>
#include <rcutils/allocator.h>
#include <rmw/rmw.h>
#include <rmw_microros/rmw_microros.h>
#include <rmw_microros/time_sync.h>
#include <rosidl_runtime_c/string_functions.h>
#include <sensor_msgs/msg/joint_state.h>
#include <uxr/client/transport.h>

#define PI_F                         3.14159265358979323846f
#define WHEEL_DIAMETER_M             0.072f
#define TRACK_WIDTH_M                0.155f
#define PWM_PERIOD_COUNTS            6400U
#define MOTOR_STOP_DUTY_PERMILLE     1000U
#define MOTOR_MIN_RPM                6.5f
#define MOTOR_MAX_RPM                30.0f
#define MOTOR_DIRECTION_DELAY_MS     300U
#define MOTOR_COMMAND_TIMEOUT_MS     200U
#define WHEEL_STATE_PERIOD_MS        100U
#define TIME_SYNC_RETRY_MS           10000U

#define FG_PPR_FL                    1115.0f
#define FG_PPR_RL                    1115.0f
#define FG_PPR_FR                    1075.0f
#define FG_PPR_RR                    1075.0f

#define LEFT_FORWARD_LEVEL           GPIO_PIN_SET
#define LEFT_REVERSE_LEVEL           GPIO_PIN_RESET
#define RIGHT_FORWARD_LEVEL          GPIO_PIN_RESET
#define RIGHT_REVERSE_LEVEL          GPIO_PIN_SET

typedef enum
{
    WHEEL_FL = 0,
    WHEEL_RL,
    WHEEL_FR,
    WHEEL_RR,
    WHEEL_COUNT
} WheelIndex;

typedef struct
{
    float rpm;
    uint16_t duty_permille;
} MotorCalibrationPoint;

typedef enum
{
    MOTOR_STATE_READY = 0,
    MOTOR_STATE_WAIT_DIRECTION
} MotorState;

TIM_HandleTypeDef htim2;
UART_HandleTypeDef huart1;

static volatile uint32_t fg_total[WHEEL_COUNT];
static volatile uint32_t fg_window[WHEEL_COUNT];
static volatile int8_t motor_direction[2];

static MotorState motor_state = MOTOR_STATE_READY;
static int8_t pending_direction[2];
static uint16_t pending_duty[2] = {1000U, 1000U};
static uint32_t direction_change_started_ms;
static uint32_t last_motor_command_ms;
static uint8_t motor_watchdog_enabled;
static uint8_t ros_time_synchronized;

static const float fg_ppr[WHEEL_COUNT] =
{
    FG_PPR_FL, FG_PPR_RL, FG_PPR_FR, FG_PPR_RR
};

static const MotorCalibrationPoint left_forward_curve[] =
{
    {5.3f,970U}, {6.8f,960U}, {8.9f,950U}, {14.2f,925U},
    {20.5f,900U}, {25.9f,875U}, {31.1f,850U}
};
static const MotorCalibrationPoint right_forward_curve[] =
{
    {6.4f,970U}, {8.5f,960U}, {10.5f,950U}, {15.9f,925U},
    {21.6f,900U}, {26.6f,875U}, {31.7f,850U}
};
static const MotorCalibrationPoint left_reverse_curve[] =
{
    {5.7f,970U}, {7.8f,960U}, {10.0f,950U}, {15.2f,925U},
    {21.6f,900U}, {26.9f,875U}, {32.2f,850U}
};
static const MotorCalibrationPoint right_reverse_curve[] =
{
    {5.5f,970U}, {7.5f,960U}, {9.5f,950U}, {14.8f,925U},
    {20.6f,900U}, {25.6f,875U}, {30.7f,850U}
};

static rcl_allocator_t allocator;
static rclc_support_t support;
static rcl_node_t node;
static rclc_executor_t executor;
static rcl_subscription_t cmd_vel_subscription;
static rcl_publisher_t wheel_state_publisher;
static geometry_msgs__msg__Twist cmd_vel_message;
static sensor_msgs__msg__JointState wheel_state_message;
static double wheel_position[WHEEL_COUNT];
static double wheel_velocity[WHEEL_COUNT];
static rosidl_runtime_c__String wheel_names[WHEEL_COUNT];

static const char *const wheel_name_text[WHEEL_COUNT] =
{
    "front_left_wheel_joint", "rear_left_wheel_joint",
    "front_right_wheel_joint", "rear_right_wheel_joint"
};

void SystemClock_Config(void);
static void MX_GPIO_Init(void);
static void MX_TIM2_Init(void);
static void MX_USART1_UART_Init(void);

bool cubemx_transport_open(struct uxrCustomTransport *transport);
bool cubemx_transport_close(struct uxrCustomTransport *transport);
size_t cubemx_transport_write(struct uxrCustomTransport *transport,
    const uint8_t *buffer, size_t length, uint8_t *error);
size_t cubemx_transport_read(struct uxrCustomTransport *transport,
    uint8_t *buffer, size_t length, int timeout_ms, uint8_t *error);
void *microros_allocate(size_t size, void *state);
void microros_deallocate(void *pointer, void *state);
void *microros_reallocate(void *pointer, size_t size, void *state);
void *microros_zero_allocate(size_t count, size_t size, void *state);

static float ClampFloat(float value, float low, float high)
{
    return value < low ? low : (value > high ? high : value);
}

static uint32_t Motor_DutyToCompare(uint16_t duty)
{
    if (duty > 1000U) duty = 1000U;
    if ((duty < 20U) && (duty != 1000U)) duty = 20U;
    return ((uint32_t)duty * PWM_PERIOD_COUNTS) / 1000U;
}

static void Motor_SetDuty(uint16_t left, uint16_t right)
{
    __HAL_TIM_SET_COMPARE(&htim2, TIM_CHANNEL_1, Motor_DutyToCompare(left));
    __HAL_TIM_SET_COMPARE(&htim2, TIM_CHANNEL_2, Motor_DutyToCompare(right));
}

static void Motor_OutputStop(void)
{
    Motor_SetDuty(MOTOR_STOP_DUTY_PERMILLE, MOTOR_STOP_DUTY_PERMILLE);
}

static void Motor_Stop(void)
{
    Motor_OutputStop();
    motor_state = MOTOR_STATE_READY;
    pending_direction[0] = 0;
    pending_direction[1] = 0;
    pending_duty[0] = MOTOR_STOP_DUTY_PERMILLE;
    pending_duty[1] = MOTOR_STOP_DUTY_PERMILLE;
}

static void Motor_SetDirection(int8_t left, int8_t right)
{
    if (left > 0) HAL_GPIO_WritePin(DIR_L_GPIO_Port, DIR_L_Pin, LEFT_FORWARD_LEVEL);
    else if (left < 0) HAL_GPIO_WritePin(DIR_L_GPIO_Port, DIR_L_Pin, LEFT_REVERSE_LEVEL);
    if (right > 0) HAL_GPIO_WritePin(DIR_R_GPIO_Port, DIR_R_Pin, RIGHT_FORWARD_LEVEL);
    else if (right < 0) HAL_GPIO_WritePin(DIR_R_GPIO_Port, DIR_R_Pin, RIGHT_REVERSE_LEVEL);
    if (left != 0) motor_direction[0] = left;
    if (right != 0) motor_direction[1] = right;
}

static uint16_t Motor_InterpolateDuty(float rpm,
    const MotorCalibrationPoint *curve, uint32_t count)
{
    if (rpm <= curve[0].rpm) return curve[0].duty_permille;
    for (uint32_t i = 1U; i < count; ++i)
    {
        if (rpm <= curve[i].rpm)
        {
            float ratio = (rpm - curve[i-1U].rpm) /
                (curve[i].rpm - curve[i-1U].rpm);
            return (uint16_t)((float)curve[i-1U].duty_permille + ratio *
                ((float)curve[i].duty_permille -
                 (float)curve[i-1U].duty_permille) + 0.5f);
        }
    }
    return curve[count-1U].duty_permille;
}

static uint16_t Motor_RPMToDuty(float rpm, bool left)
{
    const MotorCalibrationPoint *curve;
    uint32_t count;
    float magnitude = rpm < 0.0f ? -rpm : rpm;
    magnitude = ClampFloat(magnitude, MOTOR_MIN_RPM, MOTOR_MAX_RPM);
    if (left)
    {
        curve = rpm > 0.0f ? left_forward_curve : left_reverse_curve;
        count = rpm > 0.0f ?
            sizeof(left_forward_curve)/sizeof(left_forward_curve[0]) :
            sizeof(left_reverse_curve)/sizeof(left_reverse_curve[0]);
    }
    else
    {
        curve = rpm > 0.0f ? right_forward_curve : right_reverse_curve;
        count = rpm > 0.0f ?
            sizeof(right_forward_curve)/sizeof(right_forward_curve[0]) :
            sizeof(right_reverse_curve)/sizeof(right_reverse_curve[0]);
    }
    return Motor_InterpolateDuty(magnitude, curve, count);
}

static void Motor_SetWheelRPM(float left_rpm, float right_rpm)
{
    int8_t direction[2] = {
        left_rpm > 0.0f ? 1 : (left_rpm < 0.0f ? -1 : 0),
        right_rpm > 0.0f ? 1 : (right_rpm < 0.0f ? -1 : 0)
    };
    uint16_t duty[2] = {
        direction[0] == 0 ? 1000U : Motor_RPMToDuty(left_rpm, true),
        direction[1] == 0 ? 1000U : Motor_RPMToDuty(right_rpm, false)
    };

    last_motor_command_ms = HAL_GetTick();
    motor_watchdog_enabled = 1U;
    if ((direction[0] == 0) && (direction[1] == 0))
    {
        Motor_Stop();
        return;
    }
    pending_direction[0] = direction[0];
    pending_direction[1] = direction[1];
    pending_duty[0] = duty[0];
    pending_duty[1] = duty[1];
    if (motor_state == MOTOR_STATE_WAIT_DIRECTION) return;
    if (((direction[0] != 0) && (direction[0] != motor_direction[0])) ||
        ((direction[1] != 0) && (direction[1] != motor_direction[1])))
    {
        Motor_OutputStop();
        direction_change_started_ms = HAL_GetTick();
        motor_state = MOTOR_STATE_WAIT_DIRECTION;
        return;
    }
    Motor_SetDirection(direction[0], direction[1]);
    Motor_SetDuty(duty[0], duty[1]);
}

static void Motor_Update(void)
{
    uint32_t now = HAL_GetTick();
    if (motor_watchdog_enabled &&
        ((now - last_motor_command_ms) > MOTOR_COMMAND_TIMEOUT_MS))
    {
        Motor_Stop();
        motor_watchdog_enabled = 0U;
        return;
    }
    if ((motor_state == MOTOR_STATE_WAIT_DIRECTION) &&
        ((now - direction_change_started_ms) >= MOTOR_DIRECTION_DELAY_MS))
    {
        Motor_SetDirection(pending_direction[0], pending_direction[1]);
        Motor_SetDuty(pending_duty[0], pending_duty[1]);
        motor_state = MOTOR_STATE_READY;
    }
}

static void UpdateHeaderStamp(void)
{
    if (!ros_time_synchronized) return;
    int64_t epoch_ns = rmw_uros_epoch_nanos();
    if (epoch_ns <= 0) return;
    wheel_state_message.header.stamp.sec = (int32_t)(epoch_ns / 1000000000LL);
    wheel_state_message.header.stamp.nanosec =
        (uint32_t)(epoch_ns % 1000000000LL);
}

static void CmdVel_Callback(const void *input)
{
    const geometry_msgs__msg__Twist *msg = input;
    float linear = ClampFloat((float)msg->linear.x, -0.1131f, 0.1131f);
    float angular = ClampFloat((float)msg->angular.z, -1.45f, 1.45f);
    float left_mps = linear - angular * TRACK_WIDTH_M * 0.5f;
    float right_mps = linear + angular * TRACK_WIDTH_M * 0.5f;
    float rpm_factor = 60.0f / (PI_F * WHEEL_DIAMETER_M);
    float left_rpm = left_mps * rpm_factor;
    float right_rpm = right_mps * rpm_factor;
    float scale = 1.0f;
    float maximum = left_rpm < 0.0f ? -left_rpm : left_rpm;
    float right_abs = right_rpm < 0.0f ? -right_rpm : right_rpm;
    if (right_abs > maximum) maximum = right_abs;
    if (maximum > MOTOR_MAX_RPM) scale = MOTOR_MAX_RPM / maximum;
    Motor_SetWheelRPM(left_rpm * scale, right_rpm * scale);
    HAL_GPIO_WritePin(LED_GPIO_Port, LED_Pin,
        (left_rpm == 0.0f && right_rpm == 0.0f) ? GPIO_PIN_SET : GPIO_PIN_RESET);
}

static void FG_UpdateAndPublish(uint32_t elapsed_ms)
{
    uint32_t pulses[WHEEL_COUNT];
    int8_t direction[WHEEL_COUNT];
    __disable_irq();
    for (uint32_t i = 0U; i < WHEEL_COUNT; ++i)
    {
        pulses[i] = fg_window[i];
        fg_window[i] = 0U;
    }
    direction[WHEEL_FL] = motor_direction[0];
    direction[WHEEL_RL] = motor_direction[0];
    direction[WHEEL_FR] = motor_direction[1];
    direction[WHEEL_RR] = motor_direction[1];
    __enable_irq();

    for (uint32_t i = 0U; i < WHEEL_COUNT; ++i)
    {
        double delta = ((double)pulses[i] * 2.0 * (double)PI_F /
            (double)fg_ppr[i]) * (double)direction[i];
        wheel_position[i] += delta;
        wheel_velocity[i] = delta * 1000.0 / (double)elapsed_ms;
    }
    UpdateHeaderStamp();
    (void)rcl_publish(&wheel_state_publisher, &wheel_state_message, NULL);
}

static bool MicroROS_Init(void)
{
    if (rmw_uros_set_custom_transport(true, &huart1,
        cubemx_transport_open, cubemx_transport_close,
        cubemx_transport_write, cubemx_transport_read) != RMW_RET_OK) return false;

    allocator = rcutils_get_zero_initialized_allocator();
    allocator.allocate = microros_allocate;
    allocator.deallocate = microros_deallocate;
    allocator.reallocate = microros_reallocate;
    allocator.zero_allocate = microros_zero_allocate;
    if (!rcutils_set_default_allocator(&allocator)) return false;
    if (rclc_support_init(&support, 0, NULL, &allocator) != RCL_RET_OK) return false;
    ros_time_synchronized =
        (rmw_uros_sync_session(1000U) == RMW_RET_OK) ? 1U : 0U;
    node = rcl_get_zero_initialized_node();
    if (rclc_node_init_default(&node, "g431_rover_base", "", &support) != RCL_RET_OK) return false;

    cmd_vel_subscription = rcl_get_zero_initialized_subscription();
    wheel_state_publisher = rcl_get_zero_initialized_publisher();
    if (rclc_subscription_init_default(&cmd_vel_subscription, &node,
        ROSIDL_GET_MSG_TYPE_SUPPORT(geometry_msgs, msg, Twist), "/cmd_vel") != RCL_RET_OK) return false;
    if (rclc_publisher_init_default(&wheel_state_publisher, &node,
        ROSIDL_GET_MSG_TYPE_SUPPORT(sensor_msgs, msg, JointState), "/wheel_states") != RCL_RET_OK) return false;

    memset(&cmd_vel_message, 0, sizeof(cmd_vel_message));
    memset(&wheel_state_message, 0, sizeof(wheel_state_message));
    wheel_state_message.position.data = wheel_position;
    wheel_state_message.position.size = WHEEL_COUNT;
    wheel_state_message.position.capacity = WHEEL_COUNT;
    wheel_state_message.velocity.data = wheel_velocity;
    wheel_state_message.velocity.size = WHEEL_COUNT;
    wheel_state_message.velocity.capacity = WHEEL_COUNT;
    wheel_state_message.name.data = wheel_names;
    wheel_state_message.name.size = WHEEL_COUNT;
    wheel_state_message.name.capacity = WHEEL_COUNT;
    for (uint32_t i = 0U; i < WHEEL_COUNT; ++i)
    {
        if (!rosidl_runtime_c__String__init(&wheel_names[i])) return false;
        if (!rosidl_runtime_c__String__assign(&wheel_names[i], wheel_name_text[i])) return false;
    }
    if (!rosidl_runtime_c__String__init(
        &wheel_state_message.header.frame_id)) return false;
    if (!rosidl_runtime_c__String__assign(
        &wheel_state_message.header.frame_id, "base_link")) return false;

    executor = rclc_executor_get_zero_initialized_executor();
    if (rclc_executor_init(&executor, &support.context, 1, &allocator) != RCL_RET_OK) return false;
    if (rclc_executor_add_subscription(&executor, &cmd_vel_subscription,
        &cmd_vel_message, CmdVel_Callback, ON_NEW_DATA) != RCL_RET_OK) return false;
    return true;
}

int main(void)
{
    HAL_Init();
    SystemClock_Config();
    MX_GPIO_Init();
    MX_TIM2_Init();
    MX_USART1_UART_Init();
    if (HAL_TIM_PWM_Start(&htim2, TIM_CHANNEL_1) != HAL_OK) Error_Handler();
    if (HAL_TIM_PWM_Start(&htim2, TIM_CHANNEL_2) != HAL_OK) Error_Handler();
    Motor_SetDirection(1, 1);
    Motor_Stop();
    HAL_Delay(2000U);
    if (!MicroROS_Init()) Error_Handler();

    uint32_t last_wheel_ms = HAL_GetTick();
    uint32_t last_time_sync_ms = HAL_GetTick();
    while (1)
    {
        (void)rclc_executor_spin_some(&executor, RCL_MS_TO_NS(1));
        Motor_Update();
        uint32_t now = HAL_GetTick();
        if ((now - last_wheel_ms) >= WHEEL_STATE_PERIOD_MS)
        {
            uint32_t elapsed = now - last_wheel_ms;
            last_wheel_ms = now;
            FG_UpdateAndPublish(elapsed);
        }
        if (!ros_time_synchronized &&
            ((now - last_time_sync_ms) >= TIME_SYNC_RETRY_MS))
        {
            last_time_sync_ms = now;
            ros_time_synchronized =
                (rmw_uros_sync_session(100U) == RMW_RET_OK) ? 1U : 0U;
        }
        HAL_Delay(1U);
    }
}

void SystemClock_Config(void)
{
    RCC_OscInitTypeDef osc = {0};
    RCC_ClkInitTypeDef clk = {0};
    HAL_PWREx_ControlVoltageScaling(PWR_REGULATOR_VOLTAGE_SCALE1_BOOST);
    osc.OscillatorType = RCC_OSCILLATORTYPE_HSI;
    osc.HSIState = RCC_HSI_ON;
    osc.HSICalibrationValue = RCC_HSICALIBRATION_DEFAULT;
    osc.PLL.PLLState = RCC_PLL_ON;
    osc.PLL.PLLSource = RCC_PLLSOURCE_HSI;
    osc.PLL.PLLM = RCC_PLLM_DIV2;
    osc.PLL.PLLN = 40;
    osc.PLL.PLLP = RCC_PLLP_DIV2;
    osc.PLL.PLLQ = RCC_PLLQ_DIV2;
    osc.PLL.PLLR = RCC_PLLR_DIV2;
    if (HAL_RCC_OscConfig(&osc) != HAL_OK) Error_Handler();
    clk.ClockType = RCC_CLOCKTYPE_HCLK | RCC_CLOCKTYPE_SYSCLK |
        RCC_CLOCKTYPE_PCLK1 | RCC_CLOCKTYPE_PCLK2;
    clk.SYSCLKSource = RCC_SYSCLKSOURCE_PLLCLK;
    clk.AHBCLKDivider = RCC_SYSCLK_DIV1;
    clk.APB1CLKDivider = RCC_HCLK_DIV1;
    clk.APB2CLKDivider = RCC_HCLK_DIV1;
    if (HAL_RCC_ClockConfig(&clk, FLASH_LATENCY_4) != HAL_OK) Error_Handler();
}

static void MX_TIM2_Init(void)
{
    TIM_MasterConfigTypeDef master = {0};
    TIM_OC_InitTypeDef oc = {0};
    htim2.Instance = TIM2;
    htim2.Init.Prescaler = 0;
    htim2.Init.CounterMode = TIM_COUNTERMODE_UP;
    htim2.Init.Period = 6399;
    htim2.Init.ClockDivision = TIM_CLOCKDIVISION_DIV1;
    htim2.Init.AutoReloadPreload = TIM_AUTORELOAD_PRELOAD_ENABLE;
    if (HAL_TIM_PWM_Init(&htim2) != HAL_OK) Error_Handler();
    master.MasterOutputTrigger = TIM_TRGO_RESET;
    master.MasterSlaveMode = TIM_MASTERSLAVEMODE_DISABLE;
    if (HAL_TIMEx_MasterConfigSynchronization(&htim2, &master) != HAL_OK) Error_Handler();
    oc.OCMode = TIM_OCMODE_PWM1;
    oc.Pulse = 0;
    oc.OCPolarity = TIM_OCPOLARITY_HIGH;
    oc.OCFastMode = TIM_OCFAST_DISABLE;
    if (HAL_TIM_PWM_ConfigChannel(&htim2, &oc, TIM_CHANNEL_1) != HAL_OK) Error_Handler();
    if (HAL_TIM_PWM_ConfigChannel(&htim2, &oc, TIM_CHANNEL_2) != HAL_OK) Error_Handler();
    HAL_TIM_MspPostInit(&htim2);
}

static void MX_USART1_UART_Init(void)
{
    huart1.Instance = USART1;
    huart1.Init.BaudRate = 115200;
    huart1.Init.WordLength = UART_WORDLENGTH_8B;
    huart1.Init.StopBits = UART_STOPBITS_1;
    huart1.Init.Parity = UART_PARITY_NONE;
    huart1.Init.Mode = UART_MODE_TX_RX;
    huart1.Init.HwFlowCtl = UART_HWCONTROL_NONE;
    huart1.Init.OverSampling = UART_OVERSAMPLING_16;
    huart1.Init.OneBitSampling = UART_ONE_BIT_SAMPLE_DISABLE;
    huart1.Init.ClockPrescaler = UART_PRESCALER_DIV1;
    huart1.AdvancedInit.AdvFeatureInit = UART_ADVFEATURE_NO_INIT;
    if (HAL_UART_Init(&huart1) != HAL_OK) Error_Handler();
    if (HAL_UARTEx_SetTxFifoThreshold(&huart1, UART_TXFIFO_THRESHOLD_1_8) != HAL_OK) Error_Handler();
    if (HAL_UARTEx_SetRxFifoThreshold(&huart1, UART_RXFIFO_THRESHOLD_1_8) != HAL_OK) Error_Handler();
    if (HAL_UARTEx_DisableFifoMode(&huart1) != HAL_OK) Error_Handler();
}

static void MX_GPIO_Init(void)
{
    GPIO_InitTypeDef gpio = {0};
    __HAL_RCC_GPIOC_CLK_ENABLE();
    __HAL_RCC_GPIOA_CLK_ENABLE();
    __HAL_RCC_GPIOB_CLK_ENABLE();
    HAL_GPIO_WritePin(LED_GPIO_Port, LED_Pin, GPIO_PIN_SET);
    HAL_GPIO_WritePin(GPIOA, DIR_L_Pin | DIR_R_Pin, GPIO_PIN_RESET);
    gpio.Pin = LED_Pin;
    gpio.Mode = GPIO_MODE_OUTPUT_PP;
    gpio.Pull = GPIO_NOPULL;
    gpio.Speed = GPIO_SPEED_FREQ_LOW;
    HAL_GPIO_Init(LED_GPIO_Port, &gpio);
    gpio.Pin = DIR_L_Pin | DIR_R_Pin;
    HAL_GPIO_Init(GPIOA, &gpio);
    gpio.Pin = FG_FL_Pin | FG_RL_Pin;
    gpio.Mode = GPIO_MODE_IT_RISING;
    gpio.Pull = GPIO_NOPULL;
    HAL_GPIO_Init(GPIOA, &gpio);
    gpio.Pin = FG_RR_Pin | FG_FR_Pin;
    HAL_GPIO_Init(GPIOB, &gpio);
    HAL_NVIC_SetPriority(EXTI0_IRQn, 0, 0); HAL_NVIC_EnableIRQ(EXTI0_IRQn);
    HAL_NVIC_SetPriority(EXTI1_IRQn, 0, 0); HAL_NVIC_EnableIRQ(EXTI1_IRQn);
    HAL_NVIC_SetPriority(EXTI4_IRQn, 0, 0); HAL_NVIC_EnableIRQ(EXTI4_IRQn);
    HAL_NVIC_SetPriority(EXTI9_5_IRQn, 0, 0); HAL_NVIC_EnableIRQ(EXTI9_5_IRQn);
}

void HAL_GPIO_EXTI_Callback(uint16_t pin)
{
    WheelIndex wheel;
    if (pin == FG_FL_Pin) wheel = WHEEL_FL;
    else if (pin == FG_RL_Pin) wheel = WHEEL_RL;
    else if (pin == FG_FR_Pin) wheel = WHEEL_FR;
    else if (pin == FG_RR_Pin) wheel = WHEEL_RR;
    else return;
    fg_total[wheel]++;
    fg_window[wheel]++;
}

void Error_Handler(void)
{
    if (htim2.Instance == TIM2)
    {
        Motor_OutputStop();
    }
    HAL_GPIO_WritePin(LED_GPIO_Port, LED_Pin, GPIO_PIN_RESET);
    __disable_irq();
    while (1) {}
}

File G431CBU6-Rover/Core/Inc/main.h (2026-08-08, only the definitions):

#define LED_Pin GPIO_PIN_13
#define LED_GPIO_Port GPIOC
#define PWM_L_Pin GPIO_PIN_0
#define PWM_L_GPIO_Port GPIOA
#define PWM_R_Pin GPIO_PIN_1
#define PWM_R_GPIO_Port GPIOA
#define DIR_L_Pin GPIO_PIN_2
#define DIR_L_GPIO_Port GPIOA
#define DIR_R_Pin GPIO_PIN_3
#define DIR_R_GPIO_Port GPIOA
#define FG_FL_Pin GPIO_PIN_4
#define FG_FL_GPIO_Port GPIOA
#define FG_FL_EXTI_IRQn EXTI4_IRQn
#define FG_RL_Pin GPIO_PIN_6
#define FG_RL_GPIO_Port GPIOA
#define FG_RL_EXTI_IRQn EXTI9_5_IRQn
#define FG_RR_Pin GPIO_PIN_0
#define FG_RR_GPIO_Port GPIOB
#define FG_RR_EXTI_IRQn EXTI0_IRQn
#define FG_FR_Pin GPIO_PIN_1
#define FG_FR_GPIO_Port GPIOB
#define FG_FR_EXTI_IRQn EXTI1_IRQn

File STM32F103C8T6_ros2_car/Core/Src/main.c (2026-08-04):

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
/* Includes ------------------------------------------------------------------*/
#include "main.h"

/* USER CODE BEGIN Includes */
#include <stdio.h>
#include <string.h>

#include "jc_motor.h"
#include "oled.h"
/* USER CODE END Includes */

CAN_HandleTypeDef hcan;
I2C_HandleTypeDef hi2c1;

TIM_HandleTypeDef htim2;

UART_HandleTypeDef huart2;
DMA_HandleTypeDef hdma_usart2_rx;
DMA_HandleTypeDef hdma_usart2_tx;

/* USER CODE BEGIN PV */
volatile uint32_t app_tick = 0U;

volatile uint8_t uart_rx_byte = 0U;


/*
 * ============================================================
 * MOTOR TARGET
 * ============================================================
 */

static volatile float left_target_rpm = 0.0f;
static volatile float right_target_rpm = 0.0f;


/*
 * ============================================================
 * COMMAND WATCHDOG
 * ============================================================
 */

static volatile uint32_t last_cmd_ms = 0U;

static volatile uint8_t cmd_watchdog_active = 1U;


/*
 * ============================================================
 * UART
 * ============================================================
 */

#define UART_CMD_BUFFER_SIZE    64U

static char uart_cmd_buffer[
    UART_CMD_BUFFER_SIZE
];

static volatile uint8_t uart_cmd_index = 0U;


/*
 * ============================================================
 * SYSTEM STATUS
 * ============================================================
 */

static volatile uint8_t can_started = 0U;

static volatile uint8_t uart_command_seen = 0U;


/*
 * ============================================================
 * ROCK 5C
 * ============================================================
 */

#define ROCK_TIMEOUT_MS         15000U

static char rock_ip[24] =
    "192.168.xxx.xxx";

static volatile uint32_t last_rock_ms = 0U;

static volatile uint8_t rock_seen = 0U;


/*
 * ============================================================
 * CONFIGURATION
 * ============================================================
 */

#define LEFT_FORWARD_SIGN       (+1.0f)
#define RIGHT_FORWARD_SIGN      (-1.0f)

#define MANUAL_DRIVE_RPM        50.0f
#define MANUAL_TURN_RPM         40.0f

#define COMMAND_TIMEOUT_MS      300U

#define MOTOR_TIMEOUT_MS        100U

#define TELEMETRY_PERIOD_MS     20U

#define OLED_PERIOD_MS          200U

#define ROBOT_MAX_WHEEL_RPM  50.0f
/* USER CODE END PV */

void SystemClock_Config(void);
static void MX_GPIO_Init(void);
static void MX_DMA_Init(void);
static void MX_CAN_Init(void);
static void MX_I2C1_Init(void);
static void MX_TIM2_Init(void);
static void MX_USART2_UART_Init(void);
/* USER CODE BEGIN 0 */
static void Robot_SetWheelRpm(
    float left_rpm,
    float right_rpm)
{
    left_target_rpm = left_rpm;
    right_target_rpm = right_rpm;
}

static void Robot_Stop(void)
{
    Robot_SetWheelRpm(
        0.0f,
        0.0f
    );
}

static void Robot_Forward(void)
{
    Robot_SetWheelRpm(
        LEFT_FORWARD_SIGN *
            MANUAL_DRIVE_RPM,

        RIGHT_FORWARD_SIGN *
            MANUAL_DRIVE_RPM
    );
}

static void Robot_Backward(void)
{
    Robot_SetWheelRpm(
        -LEFT_FORWARD_SIGN *
            MANUAL_DRIVE_RPM,

        -RIGHT_FORWARD_SIGN *
            MANUAL_DRIVE_RPM
    );
}

static void Robot_TurnLeft(void)
{
    Robot_SetWheelRpm(
        -LEFT_FORWARD_SIGN *
            MANUAL_TURN_RPM,

        RIGHT_FORWARD_SIGN *
            MANUAL_TURN_RPM
    );
}

static void Robot_TurnRight(void)
{
    Robot_SetWheelRpm(
        LEFT_FORWARD_SIGN *
            MANUAL_TURN_RPM,

        -RIGHT_FORWARD_SIGN *
            MANUAL_TURN_RPM
    );
}


/*
 * Mark a command as valid.
 *
 * This kicks the command watchdog.
 */
static void Robot_CommandReceived(void)
{
    last_cmd_ms = HAL_GetTick();

    cmd_watchdog_active = 0U;

    uart_command_seen = 1U;
}

/*
 * Formal ROS-ready UART command:
 *
 * V,<left_rpm_x100>,<right_rpm_x100>
 *
 * Examples:
 *
 * V,5000,-5000
 *   left  = +50.00 rpm
 *   right = -50.00 rpm
 *
 * V,0,0
 *   stop
 */
static void Robot_ParseVelocityCommand(
    const char *line)
{
    long left_raw;
    long right_raw;

    if (sscanf(
            line,
            "V,%ld,%ld",
            &left_raw,
            &right_raw) == 2)
    {
        /*
         * UART protocol uses rpm * 100.
         */
        float left_rpm =
            (float)left_raw / 100.0f;

        float right_rpm =
            (float)right_raw / 100.0f;

        /*
         * Safety clamp at UART boundary.
         */
        if (left_rpm > ROBOT_MAX_WHEEL_RPM)
        {
            left_rpm = ROBOT_MAX_WHEEL_RPM;
        }

        if (left_rpm < -ROBOT_MAX_WHEEL_RPM)
        {
            left_rpm = -ROBOT_MAX_WHEEL_RPM;
        }

        if (right_rpm > ROBOT_MAX_WHEEL_RPM)
        {
            right_rpm = ROBOT_MAX_WHEEL_RPM;
        }

        if (right_rpm < -ROBOT_MAX_WHEEL_RPM)
        {
            right_rpm = -ROBOT_MAX_WHEEL_RPM;
        }

        Robot_SetWheelRpm(
            left_rpm,
            right_rpm
        );

        Robot_CommandReceived();

        char message[96];

        int length = snprintf(
            message,
            sizeof(message),

            "[CMD] V L=%.2f R=%.2f rpm\r\n",

            left_rpm,
            right_rpm
        );

        if (length > 0)
        {
            HAL_UART_Transmit(
                &huart2,
                (uint8_t *)message,
                (uint16_t)length,
                100U
            );
        }
    }
}


/*
 * Debug keyboard commands.
 *
 * These are intentionally retained for bench testing.
 */
static void Robot_HandleSingleCommand(
    uint8_t command)
{
    switch (command)
    {
        case 'w':
        case 'W':

            Robot_Forward();
            Robot_CommandReceived();
            break;


        case 's':
        case 'S':

            Robot_Backward();
            Robot_CommandReceived();
            break;


        case 'a':
        case 'A':

            Robot_TurnLeft();
            Robot_CommandReceived();
            break;


        case 'd':
        case 'D':

            Robot_TurnRight();
            Robot_CommandReceived();
            break;


        case 'x':
        case 'X':
        case ' ':

            Robot_Stop();
            Robot_CommandReceived();
            break;


        default:
            break;
    }
}
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

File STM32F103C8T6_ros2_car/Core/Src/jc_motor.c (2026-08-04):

#include "jc_motor.h"

extern CAN_HandleTypeDef hcan;

#define JC_TORQUE_LIMIT_NM  0.10f

JC_MotorState motor_left =
{
    .node_id = JC_NODE_LEFT,
    .pos_deg = 0.0f,
    .vel_rpm = 0.0f,
    .rx_count = 0U,
    .last_rx_ms = 0U
};

JC_MotorState motor_right =
{
    .node_id = JC_NODE_RIGHT,
    .pos_deg = 0.0f,
    .vel_rpm = 0.0f,
    .rx_count = 0U,
    .last_rx_ms = 0U
};

static uint16_t JC_TxId(uint8_t node_id)
{
    return (uint16_t)(0x600U + node_id);
}

static float JC_ClampFloat(
    float value,
    float minimum,
    float maximum)
{
    if (value > maximum)
    {
        return maximum;
    }

    if (value < minimum)
    {
        return minimum;
    }

    return value;
}

static int16_t JC_ReadBigEndianS16(
    const uint8_t *data)
{
    uint16_t value =
        ((uint16_t)data[0] << 8) |
        ((uint16_t)data[1]);

    return (int16_t)value;
}

static int32_t JC_ReadBigEndianS24(
    const uint8_t *data)
{
    int32_t value =
        ((int32_t)data[0] << 16) |
        ((int32_t)data[1] << 8) |
        ((int32_t)data[2]);

    if ((value & 0x00800000L) != 0)
    {
        value |= (int32_t)0xFF000000L;
    }

    return value;
}

static HAL_StatusTypeDef JC_Send8(
    uint16_t standard_id,
    const uint8_t data[8])
{
    CAN_TxHeaderTypeDef tx_header = {0};
    uint32_t tx_mailbox = 0U;

    if (HAL_CAN_GetTxMailboxesFreeLevel(&hcan) == 0U)
    {
        return HAL_BUSY;
    }

    tx_header.StdId = standard_id;
    tx_header.ExtId = 0U;
    tx_header.IDE = CAN_ID_STD;
    tx_header.RTR = CAN_RTR_DATA;
    tx_header.DLC = 8U;
    tx_header.TransmitGlobalTime = DISABLE;

    return HAL_CAN_AddTxMessage(
        &hcan,
        &tx_header,
        (uint8_t *)data,
        &tx_mailbox
    );
}

HAL_StatusTypeDef JC_CAN_Init(void)
{
    CAN_FilterTypeDef filter = {0};

    /*
     * POC stage:
     * Accept all CAN frames into FIFO0.
     */
    filter.FilterBank = 0U;
    filter.FilterMode = CAN_FILTERMODE_IDMASK;
    filter.FilterScale = CAN_FILTERSCALE_32BIT;

    filter.FilterIdHigh = 0x0000U;
    filter.FilterIdLow = 0x0000U;
    filter.FilterMaskIdHigh = 0x0000U;
    filter.FilterMaskIdLow = 0x0000U;

    filter.FilterFIFOAssignment = CAN_RX_FIFO0;
    filter.FilterActivation = ENABLE;
    filter.SlaveStartFilterBank = 14U;

    if (HAL_CAN_ConfigFilter(
            &hcan,
            &filter) != HAL_OK)
    {
        return HAL_ERROR;
    }

    if (HAL_CAN_Start(&hcan) != HAL_OK)
    {
        return HAL_ERROR;
    }

    if (HAL_CAN_ActivateNotification(
            &hcan,
            CAN_IT_RX_FIFO0_MSG_PENDING) != HAL_OK)
    {
        return HAL_ERROR;
    }

    return HAL_OK;
}

HAL_StatusTypeDef JC_Idle(uint8_t node_id)
{
    const uint8_t data[8] =
    {
        0x2B,
        0x00,
        0xA0,
        0x00,
        0x00,
        0x01,
        0x00,
        0x00
    };

    return JC_Send8(
        JC_TxId(node_id),
        data
    );
}

HAL_StatusTypeDef JC_EnterClosedLoop(
    uint8_t node_id)
{
    const uint8_t data[8] =
    {
        0x2B,
        0x00,
        0xA2,
        0x00,
        0x00,
        0x01,
        0x00,
        0x00
    };

    return JC_Send8(
        JC_TxId(node_id),
        data
    );
}

HAL_StatusTypeDef JC_SetMode(
    uint8_t node_id,
    uint16_t mode)
{
    uint8_t data[8] =
    {
        0x2B,
        0x00,
        0x60,
        0x00,
        0x00,
        0x00,
        0x00,
        0x00
    };

    data[4] =
        (uint8_t)((mode >> 8) & 0xFFU);

    data[5] =
        (uint8_t)(mode & 0xFFU);

    return JC_Send8(
        JC_TxId(node_id),
        data
    );
}

HAL_StatusTypeDef JC_SetTorqueNm(
    uint8_t node_id,
    float torque_nm)
{
    int16_t raw_torque;

    uint8_t data[8] =
    {
        0x2B,
        0x00,
        0x20,
        0x00,
        0x00,
        0x00,
        0x00,
        0x00
    };

    torque_nm = JC_ClampFloat(
        torque_nm,
        -JC_TORQUE_LIMIT_NM,
        JC_TORQUE_LIMIT_NM
    );

    raw_torque =
        (int16_t)(torque_nm * 100.0f);

    data[4] =
        (uint8_t)(((uint16_t)raw_torque >> 8) & 0xFFU);

    data[5] =
        (uint8_t)((uint16_t)raw_torque & 0xFFU);

    return JC_Send8(
        JC_TxId(node_id),
        data
    );
}
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

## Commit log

2026-07-27 rock 5c ros2 backup
    [minimal_box.urdf, pyvenv.cfg, simple_car.urdf]
2026-07-30 Add ld-06
    [minimal_box.urdf, pyvenv.cfg, ros_car.urdf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]
2026-08-04 add 3d model
    [base-2.step, base.step, tyre.step]
2026-08-04 radxa 5c document update
    [ros_car.urdf]
2026-08-08 basic pwm test
2026-08-08 Configure USART1 and add micro-ROS STM32 utilities
2026-08-08 Add prebuilt micro-ROS Jazzy library for STM32G431
2026-08-09 complete ros2 based G431 microros board

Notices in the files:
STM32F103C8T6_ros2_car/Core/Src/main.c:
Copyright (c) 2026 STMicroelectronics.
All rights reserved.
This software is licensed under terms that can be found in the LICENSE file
